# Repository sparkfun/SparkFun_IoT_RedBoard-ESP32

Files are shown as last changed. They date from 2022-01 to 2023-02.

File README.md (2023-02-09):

SparkFun IoT RedBoard - ESP32
========================================

SparkFun IoT RedBoard - ESP32 (https://www.sparkfun.com/products/19177)

[*SparkFun IoT RedBoard - ESP32 (WRL-19177)*](https://www.sparkfun.com/products/19177)

The [SparkFun IoT RedBoard](www.sparkfun.com/products/19177) is an ESP32 Development Board that includes everything but the kitchen sink! Espressif's ESP32 WROOM is a powerful WiFi and Bluetooth® MCU module that targets a wide variety of applications. At the core of this module is the ESP32-D0WDQ6 chip which is designed to be both scalable and adaptive. The IoT RedBoard can target a wide variety of applications, ranging from low-power sensor networks to the most demanding tasks, such as voice encoding, music streaming, and MP3 decoding. The IoT ReadBoard also utilizes our handy Qwiic Connect System which means no soldering or shields are required to connect it to the rest of your system!

The USB-to-serial is achieved with a USB-C connector with through hole anchoring and the ubiquitous CH340G requiring fewer driver installs. We've included 3.3V voltage translation and a [Qwiic connector](https://www.sparkfun.com/qwiic) to the edge of the board to allow for quick and seamless connection to our ever-growing line of I<sup>2</sup>C based [Qwiic products](https://www.sparkfun.com/qwiic#products). The board even includes a microSD socket if your application requires you to log and save data to a memory card.

The operating system is freeRTOS with LwIP; TLS 1.2 with hardware acceleration is built in as well. Secure (encrypted) over the air (OTA) upgrade is also supported, so that users can upgrade their products even after their release, at minimum cost and effort.

Repository Contents
-------------------

* **/Documents** - Data sheets, additional product information
* **/Hardware** - Eagle design files (.brd, .sch)

Documentation
--------------
* **[SparkFun Fritzing Part](https://github.com/sparkfun/Fritzing_Parts/blob/main/products/19177_sfe_iot_redboard_esp32_development_board.fzpz)** - Fritzing diagrams for SparkFun products.
* **[Hookup Guide](https://learn.sparkfun.com/tutorials/iot-redboard-esp32-development-board-hookup-guide)** - Basic hookup guide for the SparkFun IoT RedBoard ESP32.

License Information
-------------------

This product is _**open source**_! 

Please review the LICENSE.md file for license information. 

If you have any questions or concerns on licensing, please contact technical support on our [SparkFun forums](https://forum.sparkfun.com/viewforum.php?f=152).

Distributed as-is; no warranty is given.

- Your friends at SparkFun.

_<COLLABORATION CREDIT>_

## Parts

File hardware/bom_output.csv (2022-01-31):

Qty | PROD_ID | Names | Value | Package
9 | CAP-00810 | C1; C2; C4; C5; C7; C11; C12; C13; C17 | 0.1uF | 0603
2 | CAP-11015 | C3; C14 | 10uF | 0603
2 | CAP-00811 | C6; C10 | 10uF | EIA3216
1 | CAP-00867 | C8 | 10nF | 0603
1 | CAP-08478 | C9 | 47uF | PANASONIC_D
2 | CAP-14106 | C15; C16 | 4.7uF | 0603
1 | DIO-08053 | D1 | 1A/40V/500mV | SMA-DIODE
1 | DIO-00862 | D2 | GREEN | LED-1206-HIDDENSILK
1 | DIO-09909 | D3 | YELLOW | LED-1206-HIDDENSILK
1 | DIO-09912 | D4 | RED | LED-1206-HIDDENSILK
1 | DIO-00862 | D5 | PWR | LED-1206-HIDDENSILK
1 | DIO-09911 | D6 | BLUE | LED-1206-HIDDENSILK
1 | RES-14313 | F1 | 6V/2A | 1210
1 | CONN-08106 | J1 | 5.5x2.1mm Barrel | POWER_JACK_SMD
1 | CONN-14122 | J2 | USB C | USB-C-16P-2LAYER-PADS
1 | CONN-11219 | J5 | M10NO_SILK | 1X10_NO_SILK
1 | CONN-11219 | J6 |  | 1X10_SMD_COMBINED
2 | CONN-08438 | J7; J9 |  | 1X08_NO_SILK
2 | CONN-10204 | J8; J10 |  | 1X08_SMD_COMBINED
1 | CONN-08437 | J11 |  | 1X06_NO_SILK
1 | CONN-10203 | J12 |  | 1X06_SMD_STRAIGHT_COMBO
1 | CONN-13694 | J13 | QWIIC_RIGHT_ANGLE | JST04_1MM_RA
1 | CONN-16110 | J15 | MICRO-SD-PUSH-PUSH-EXT-PIN | MICROSD-EXTERNALPIN
1 | CONN-11443 | JP2 | LiPo | JST-2-SMD
1 | TRANS-13337 | Q1 | MBT3904DW1T1 | SC70-6
1 | TRANS-13337 | Q2 |  | SC70-6
6 | TRANS-14388 | Q3; Q5; Q7; Q9; Q11; Q13 | 20V/4.2A/52mΩ/1.4W | SOT23-3
5 | TRANS-14386 | Q4; Q6; Q8; Q10; Q12 |  | SOT363_PHILIPS
13 | RES-00824 | R1; R6; R7; R8; R12; R13; R14; R15; R17; R19; R23; R24; R26 | 10k | 0603
2 | RES-12083 | R2; R3 | 5.1k | 0603
3 | RES-07857 | R4; R5; R9 | 4.7k | 0603
1 | RES-07849 | R10 | 240 | 0603
1 | RES-07850 | R11 | 715 | 0603
5 | RES-07871 | R16; R18; R20; R25; R27 | 47k | 0603
1 | RES-07856 | R21 | 1k | 0603
1 | RES-08296 | R22 | 2.0k | 0603
2 | RES-08272 | R28; R29 | 2.2k | 0603
1 | RES-07863 | R30 | 100 | 0603
1 | SWCH-14139 | S1 | Reset | TACTILE_SWITCH_SMD_5.2MM
1 | SWCH-14139 | S2 | GPIO0 | TACTILE_SWITCH_SMD_5.2MM
1 | IC-15676 | U1 | ESP-WROOM-3232D-NARROW | ESP-WROOM-32D-NARROW
1 | IC-14038 | U2 | CH340C | SO016
1 | VREG-08170 | U3 | LM1117 | SOT223
1 | VREG-12457 | U4 | 3.3V | SOT23-5
1 | IC-09995 | U5 | MCP73831 | SOT23-5
1 | IC-12551 | U6 | MAX17048 | DFN-8

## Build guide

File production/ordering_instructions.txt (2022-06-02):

panel size, 394x132mm
PCB thickness, 1.6mm
number of layers, 4
soldermask color, Red
silkscreen color, White
oz copper, 1oz
finish, HASL lead free
stencils, top
pcs per panel, 10
min trace width, 0.1778mm / 0.0070in
min drill size, 0.3048mm / 0.0120in
filename to layer stackup 1/2/3/4: GTL, GL2, GL3, GBL

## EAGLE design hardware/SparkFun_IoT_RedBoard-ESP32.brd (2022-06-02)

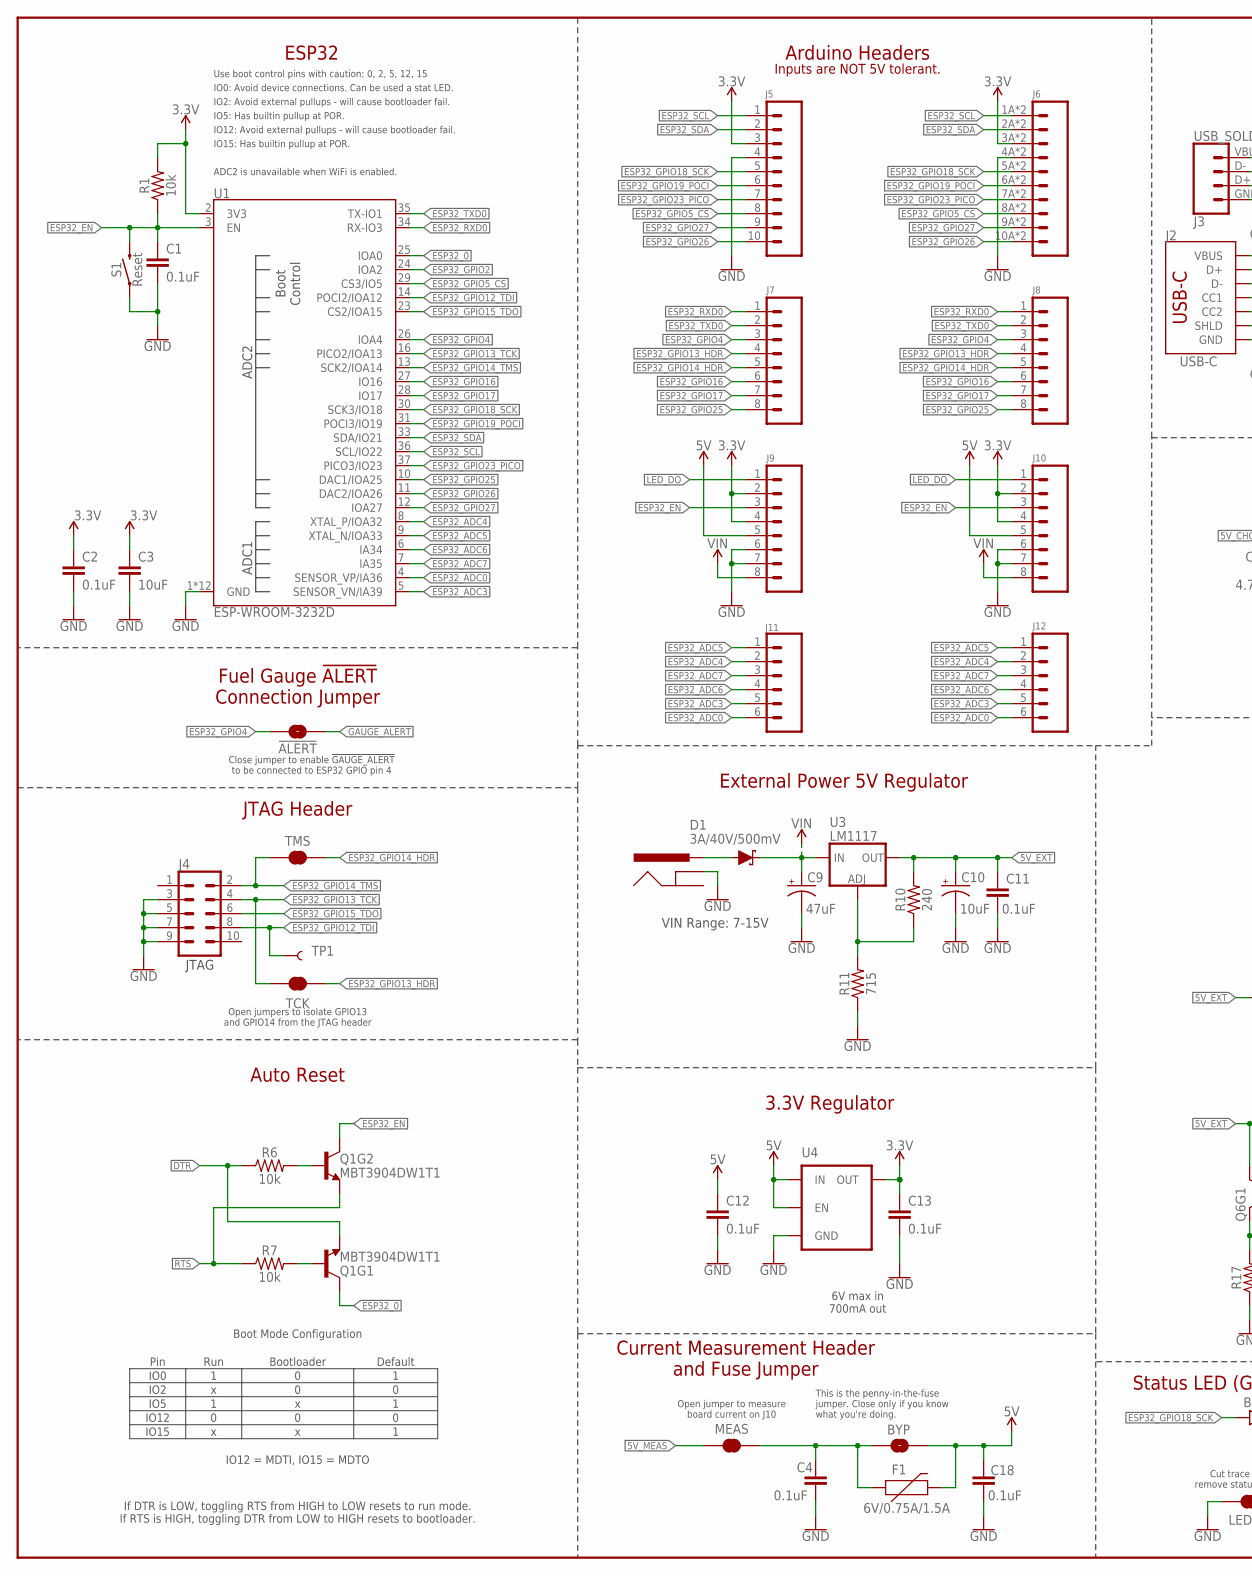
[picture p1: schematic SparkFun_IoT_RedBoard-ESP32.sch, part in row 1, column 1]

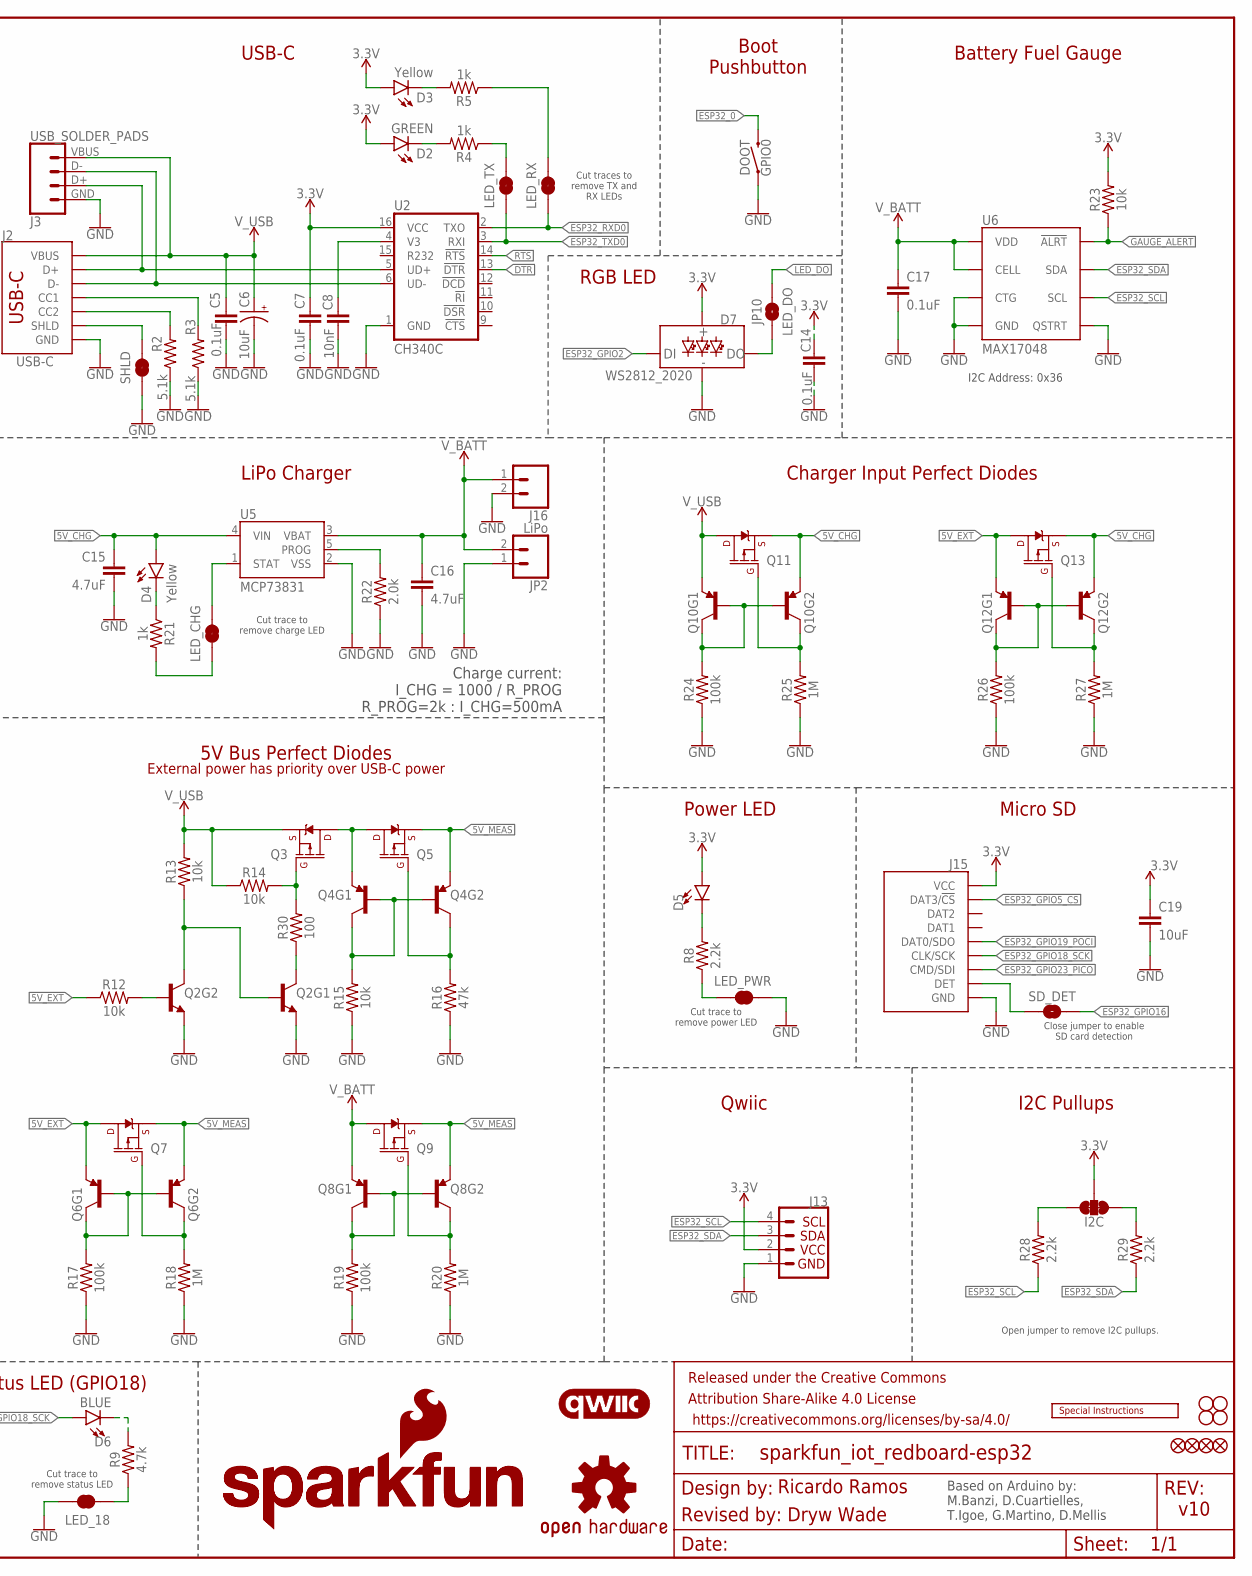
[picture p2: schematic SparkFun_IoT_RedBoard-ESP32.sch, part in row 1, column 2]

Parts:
!ALERT!: JUMPER-SMT_2_NO_SILK; SMT-JUMPER_2_NO_SILK
BYP: JUMPER-SMT_2_NO_SILK; SMT-JUMPER_2_NO_SILK
C1, C2, C4, C5, C7, C11, C12, C13, C14, C17, C18: 0.1uF; 0603
C3, C19: 10uF; 0603
C6, C10: 10uF; EIA3216
C8: 10nF; 0603
C9: 47uF; PANASONIC_D
C15, C16: 4.7uF; 0603
D1: 3A/40V/500mV; SMA-DIODE
D2: GREEN; LED-1206
D3, D4: Yellow; LED-1206
D5: RED; LED-1206
D6: BLUE; LED-1206
D7: WS2812_2020; WS2812-2020
DOOT: GPIO0; TACTILE_SWITCH_SMD_5.2MM
F1: 6V/0.75A/1.5A; 1206
FRAME1: FRAME-LEDGER; CREATIVE_COMMONS
I2C: JUMPER-SMT_3_2-NC_TRACE_SILK; SMT-JUMPER_3_2-NC_TRACE_SILK
J1: 5.5x2.1mm Barrel; POWER_JACK_SMD
J2: USB-C; USB-C-16P-4LAYER-ISOLATED
J3: USB_SOLDER_PADS; USB-SOLDER-PADS
J4: CONN_05X20.05_IN_PTH_SILK; 2X5_PTH_SILK_.05
J5: M10NO_SILK; 1X10_NO_SILK
J6: CONN_10SMD_COMBO-FEMALE; 1X10_SMD_COMBINED
J7, J9: CONN_08NO_SILK_FEMALE_PTH; 1X08_NO_SILK
J8, J10: CONN_08SMD-COMBO-FEMALE; 1X08_SMD_COMBINED
J11: CONN_06NO_SILK_FEMALE_PTH; 1X06_NO_SILK
J12: CONN_06SMD-STRAIGHT-COMBO-FEMALE; 1X06_SMD_STRAIGHT_COMBO
J13: QWIIC_RIGHT_ANGLE; JST04_1MM_RA
J15: MICRO-SD-PUSH-PUSH-EXT-PIN; MICROSD-EXTERNALPIN
J16: CONN_021X02_NO_SILK; 1X02_NO_SILK
JP1, JP7, JP8, JP9: FIDUCIAL1X2; FIDUCIAL-1X2
JP2: LiPo; JST-2-SMD
JP3, JP4, JP5, JP6: STAND-OFF
JP10: LED_DO; SMT-JUMPER_2_NO_SILK
LED_18: JUMPER-SMT_2_NC_TRACE_SILK; SMT-JUMPER_2_NC_TRACE_SILK
LED_CHG: JUMPER-SMT_2_NC_TRACE_SILK; SMT-JUMPER_2_NC_TRACE_SILK
LED_PWR: JUMPER-SMT_2_NC_TRACE_SILK; SMT-JUMPER_2_NC_TRACE_SILK
LED_RX: JUMPER-SMT_2_NC_TRACE_SILK; SMT-JUMPER_2_NC_TRACE_SILK
LED_TX: JUMPER-SMT_2_NC_TRACE_SILK; SMT-JUMPER_2_NC_TRACE_SILK
LOGO1: SFE_LOGO_NAME.1_INCH; SFE_LOGO_NAME_.1
LOGO2: QWIIC_LOGO_5MM; QWIIC_5MM
LOGO3: OSHW-LOGOMINI; OSHW-LOGO-MINI
LOGO5: SPECIAL_INSTRUCTIONS-ORDERING; ORDERING_INSTRUCTIONS
LOGO6: SFE_LOGO_NAME_FLAME.2_INCH; SFE_LOGO_NAME_FLAME_.2
MEAS: JUMPER-COMBO_2_NC_TRACE; COMBO-JUMPER_2_NC_TRACE
Q1: MBT3904DW1T1; SC70-6
Q2: TRANS_NPN_DUAL-MBT3904DW1T1; SC70-6
Q3, Q5, Q7, Q9, Q11, Q13: 20V/4.2A/52mΩ/1.4W; SOT23-3
Q4, Q6, Q8, Q10, Q12: TRANS_PNP_DUALSOT-363; SOT363_PHILIPS
R1, R6, R7, R12, R13, R14, R15, R23: 10k; 0603
R2, R3: 5.1k; 0603
R4, R5, R21: 1k; 0603
R8, R28, R29: 2.2k; 0603
R9: 4.7k; 0603
R10: 240; 0603
R11: 715; 0603
R16: 47k; 0603
R17, R19, R24, R26: 100k; 0603
R18, R20, R25, R27: 1M; 0603
R22: 2.0k; 0603
R30: 100; 0603
S1: Reset; TACTILE_SWITCH_SMD_5.2MM
SD_DET: SD_DET; SMT-JUMPER_2_NO_SILK
SHLD: SHLD; SMT-JUMPER_2_NC_TRACE_SILK
TCK: JUMPER-SMT_2_NC_TRACE_SILK; SMT-JUMPER_2_NC_TRACE_SILK
TMS: JUMPER-SMT_2_NC_TRACE_SILK; SMT-JUMPER_2_NC_TRACE_SILK
TP1: TEST-POINT3; PAD.03X.03
U1: ESP-WROOM-3232D; ESP-WROOM-32D
U2: CH340C; SO016
U3: LM1117; SOT223
U4: XC6222B331MR-G; SOT23-5
U5: MCP73831; SOT23-5
U6: MAX17048; DFN-8

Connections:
3.3V: C2.1, C3.1, C7.1, C13.1, C14.1, C19.1, D2.A, D3.A, D5.A, D7.VCC, I2C.2, J5.3, J6.3A (3), J6.3B (3), J9.2, J9.4, J10.2, J10.4, J13.2, J15.4 (VCC), R1.2, R23.2, U1.2 (3V3), U2.16 (VCC), U4.5 (OUT)
5V: BYP.2, C12.1, C18.1, F1.2, J9.5, J10.5, U4.1 (IN), U4.3 (EN)
5V_CHG: C15.1, D4.A, Q10.4 (E), Q11.2 (S), Q12.4 (E), Q13.2 (S), U5.4 (VIN)
5V_EXT: C10.+, C11.1, Q6.1 (E), Q7.3 (D), Q12.1 (E), Q13.3 (D), R10.2, R12.1, U3.2 (OUT), U3.4 (OUT)
5V_MEAS: MEAS.1, MEAS.3 (1), Q4.4 (E), Q5.2 (S), Q6.4 (E), Q7.2 (S), Q8.4 (E), Q9.2 (S)
!DTR!: Q1.4 (E), R6.1, U2.13 (!DTR)
!GAUGE_ALERT!: !ALERT!.1, R23.1, U6.5 (!ALRT)
!RTS!: Q1.1 (E), R7.1, U2.14 (!RTS)
CC1: J2.A5 (CC1), R3.2
CC2: J2.B5 (CC2), R2.2
D+: J2.A6 (D+), J2.B6 (D+), J3.D+ (3), U2.5 (UD+)
D-: J2.A7 (D-), J2.B7 (D-), J3.D- (2), U2.6 (UD-)
ESP32_0: DOOT.3 (2), DOOT.4 (2), Q1.3 (C), U1.25 (IOA0)
ESP32_ADC0: J11.6, J12.6, U1.4 (SENSOR_VP/IA36)
ESP32_ADC3: J11.5, J12.5, U1.5 (SENSOR_VN/IA39)
ESP32_ADC4: J11.2, J12.2, U1.8 (XTAL_P/IOA32)
ESP32_ADC5: J11.1, J12.1, U1.9 (XTAL_N/IOA33)
ESP32_ADC6: J11.4, J12.4, U1.6 (IA34)
ESP32_ADC7: J11.3, J12.3, U1.7 (IA35)
ESP32_EN: C1.1, J9.3, J10.3, Q1.6 (C), R1.1, S1.3 (2), S1.4 (2), U1.3 (EN)
ESP32_GPIO2: D7.DI, U1.24 (IOA2)
ESP32_GPIO4: !ALERT!.2, J7.3, J8.3, U1.26 (IOA4)
ESP32_GPIO5_!CS!: J5.8, J6.8A (8), J6.8B (8), J15.2 (DAT3/!CS!), U1.29 (CS3/IO5)
ESP32_GPIO12_TDI: J4.8, TP1.1, U1.14 (POCI2/IOA12)
ESP32_GPIO13_HDR: J7.4, J8.4, TCK.2
ESP32_GPIO13_TCK: J4.4, TCK.1, U1.16 (PICO2/IOA13)
ESP32_GPIO14_HDR: J7.5, J8.5, TMS.2
ESP32_GPIO14_TMS: J4.2, TMS.1, U1.13 (SCK2/IOA14)
ESP32_GPIO15_TDO: J4.6, U1.23 (CS2/IOA15)
ESP32_GPIO16: J7.6, J8.6, SD_DET.2, U1.27 (IO16)
ESP32_GPIO17: J7.7, J8.7, U1.28 (IO17)
ESP32_GPIO18_SCK: D6.A, J5.5, J6.5A (5), J6.5B (5), J15.5 (CLK/SCK), U1.30 (SCK3/IO18)
ESP32_GPIO19_POCI: J5.6, J6.6A (6), J6.6B (6), J15.7 (DAT0/SDO), U1.31 (POCI3/IO19)
ESP32_GPIO23_PICO: J5.7, J6.7A (7), J6.7B (7), J15.3 (CMD/SDI), U1.37 (PICO3/IO23)
ESP32_GPIO25: J7.8, J8.8, U1.10 (DAC1/IOA25)
ESP32_GPIO26: J5.10, J6.10A (10), J6.10B (10), U1.11 (DAC2/IOA26)
ESP32_GPIO27: J5.9, J6.9A (9), J6.9B (9), U1.12 (IOA27)
ESP32_RXD0: J7.1, J8.1, LED_RX.1, U1.34 (RX-IO3), U2.2 (TXO)
ESP32_SCL: J5.1, J6.1A (1), J6.1B (1), J13.4, R28.1, U1.36 (SCL/IO22), U6.7 (SCL)
ESP32_SDA: J5.2, J6.2A (2), J6.2B (2), J13.3, R29.1, U1.33 (SDA/IO21), U6.8 (SDA)
ESP32_TXD0: J7.2, J8.2, LED_TX.1, U1.35 (TX-IO1), U2.3 (RXI)
GND: C1.2, C2.2, C3.2, C4.2, C5.2, C6.-, C7.2, C8.2, C9.-, C10.-, C11.2, C12.2, C13.2, C14.2, C15.2, C16.2, C17.2, C18.2, C19.2, D7.GND, DOOT.1, DOOT.2 (1), J1.GND (GNDBREAK), J2.GND, J2.GND2 (GND), J3.GND (4), J4.3, J4.5, J4.7, J4.9, J5.4, J6.4A (4), J6.4B (4), J9.6, J9.7, J10.6, J10.7, J13.1, J15.6 (GND), J15.10 (GND), J15.11 (GND), J15.12 (GND), J15.13 (GND), J16.2, JP2.1 (2), LED_18.1, LED_PWR.1, Q2.1 (E), Q2.4 (E), R2.1, R3.1, R11.1, R15.1, R16.1, R17.1, R18.1, R19.1, R20.1, R22.1, R24.1, R25.1, R26.1, R27.1, S1.1, S1.2 (1), SHLD.1, U1.1 (GND), U1.15 (GND), U1.38 (GND), U1.GND, U1.GNDT1 (GND), U1.GNDT2 (GND), U1.GNDT3 (GND), U1.GNDT4 (GND), U1.GNDT5 (GND), U1.GNDT6 (GND), U1.GNDT7 (GND), U1.GNDT8 (GND), U2.1 (GND), U4.2 (GND), U5.2 (VSS), U6.1 (CTG), U6.4 (GND), U6.6 (QSTRT), U6.9 (GND)
LED_DO: J9.1, J10.1, JP10.2
unnamed: LED_CHG.2, U5.1 (STAT)
unnamed: D5.C, R8.2
unnamed: D6.C, R9.2
unnamed: LED_CHG.1, R21.2
unnamed: D2.C, R4.2
unnamed: C8.1, U2.4 (V3)
unnamed: D3.C, R5.2
unnamed: Q6.2 (B), Q6.5 (B), Q6.6 (C), R17.2
unnamed: Q3.1 (G), R14.2, R30.2
unnamed: Q6.3 (C), Q7.1 (G), R18.2
unnamed: Q2.3 (C), R30.1
unnamed: Q4.2 (B), Q4.5 (B), Q4.6 (C), R15.2
unnamed: Q8.2 (B), Q8.5 (B), Q8.6 (C), R19.2
unnamed: R22.2, U5.5 (PROG)
unnamed: R10.1, R11.2, U3.1 (ADJ)
unnamed: Q4.3 (C), Q5.1 (G), R16.2
unnamed: Q8.3 (C), Q9.1 (G), R20.2
unnamed: I2C.3, R28.2
unnamed: BYP.1, C4.1, F1.1, MEAS.2, MEAS.4 (2)
unnamed: I2C.1, R29.2
unnamed: Q2.2 (B), R12.2
unnamed: Q2.5 (B), Q2.6 (C), R13.1
unnamed: Q10.3 (C), Q11.1 (G), R25.2
unnamed: Q1.5 (B), R7.2
unnamed: Q1.2 (B), R6.2
unnamed: Q10.2 (B), Q10.5 (B), Q10.6 (C), R24.2
unnamed: J15.9 (DET), SD_DET.1
unnamed: Q12.3 (C), Q13.1 (G), R27.2
unnamed: Q12.2 (B), Q12.5 (B), Q12.6 (C), R26.2
unnamed: LED_TX.2, R4.1
unnamed: LED_RX.2, R5.1
unnamed: D4.C, R21.1
unnamed: LED_PWR.2, R8.1
unnamed: LED_18.2, R9.1
unnamed: D7.DO, JP10.1
PWRIN: D1.A, J1.VIN0 (PWR)
SHLD: J2.SHLD1 (SHLD), J2.SHLD2 (SHLD), J2.SHLD3 (SHLD), J2.SHLD4 (SHLD), J2.SHLD5 (SHLD), J2.SHLD6 (SHLD), J2.SHLD7 (SHLD), J2.SHLD8 (SHLD), SHLD.2
VIN: C9.+, D1.C, J9.8, J10.8, U3.3 (IN)
VUSB_PROT: Q3.3 (D), Q4.1 (E), Q5.3 (D)
V_BATT: C16.1, C17.1, J16.1, JP2.2 (1), Q8.1 (E), Q9.3 (D), U5.3 (VBAT), U6.2 (CELL), U6.3 (VDD)
V_USB: C5.1, C6.+, J2.VBUS1 (VBUS), J2.VBUS2 (VBUS), J3.VBUS (1), Q3.2 (S), Q10.1 (E), Q11.3 (D), R13.2, R14.1

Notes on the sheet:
Based on Arduino by: M.Banzi, D.Cuartielles, T.Igoe, G.Martino, D.Mellis
Ricardo Ramos
v10
This is the penny-in-the-fuse jumper. Close only if you know what you're doing.
JTAG
J12
J11
J10
If DTR is LOW, toggling RTS from HIGH to LOW resets to run mode. If RTS is HIGH, toggling DTR from LOW to HIGH resets to bootloader.
VIN Range: 7-15V
6V max in 700mA out
Charge current: I_CHG = 1000 / R_PROG R_PROG=2k : I_CHG=500mA
ESP32
Arduino Headers
USB-C
Battery Fuel Gauge
LiPo Charger
Charger Input Perfect Diodes
5V Bus Perfect Diodes
Power LED
Micro SD
Qwiic
I2C Pullups
External Power 5V Regulator
3.3V Regulator
JTAG Header
Fuel Gauge !ALERT! Connection Jumper
Auto Reset
Current Measurement Header and Fuse Jumper
Boot Pushbutton
Status LED (GPIO18)
External power has priority over USB-C power
Inputs are NOT 5V tolerant.
I2C Address: 0x36
Open jumpers to isolate GPIO13 and GPIO14 from the JTAG header
Close jumper to enable !GAUGE_ALERT! to be connected to ESP32 GPIO pin 4
Open jumper to measure board current on J10
Open jumper to remove I2C pullups.
Revised by: Dryw Wade
RGB LED

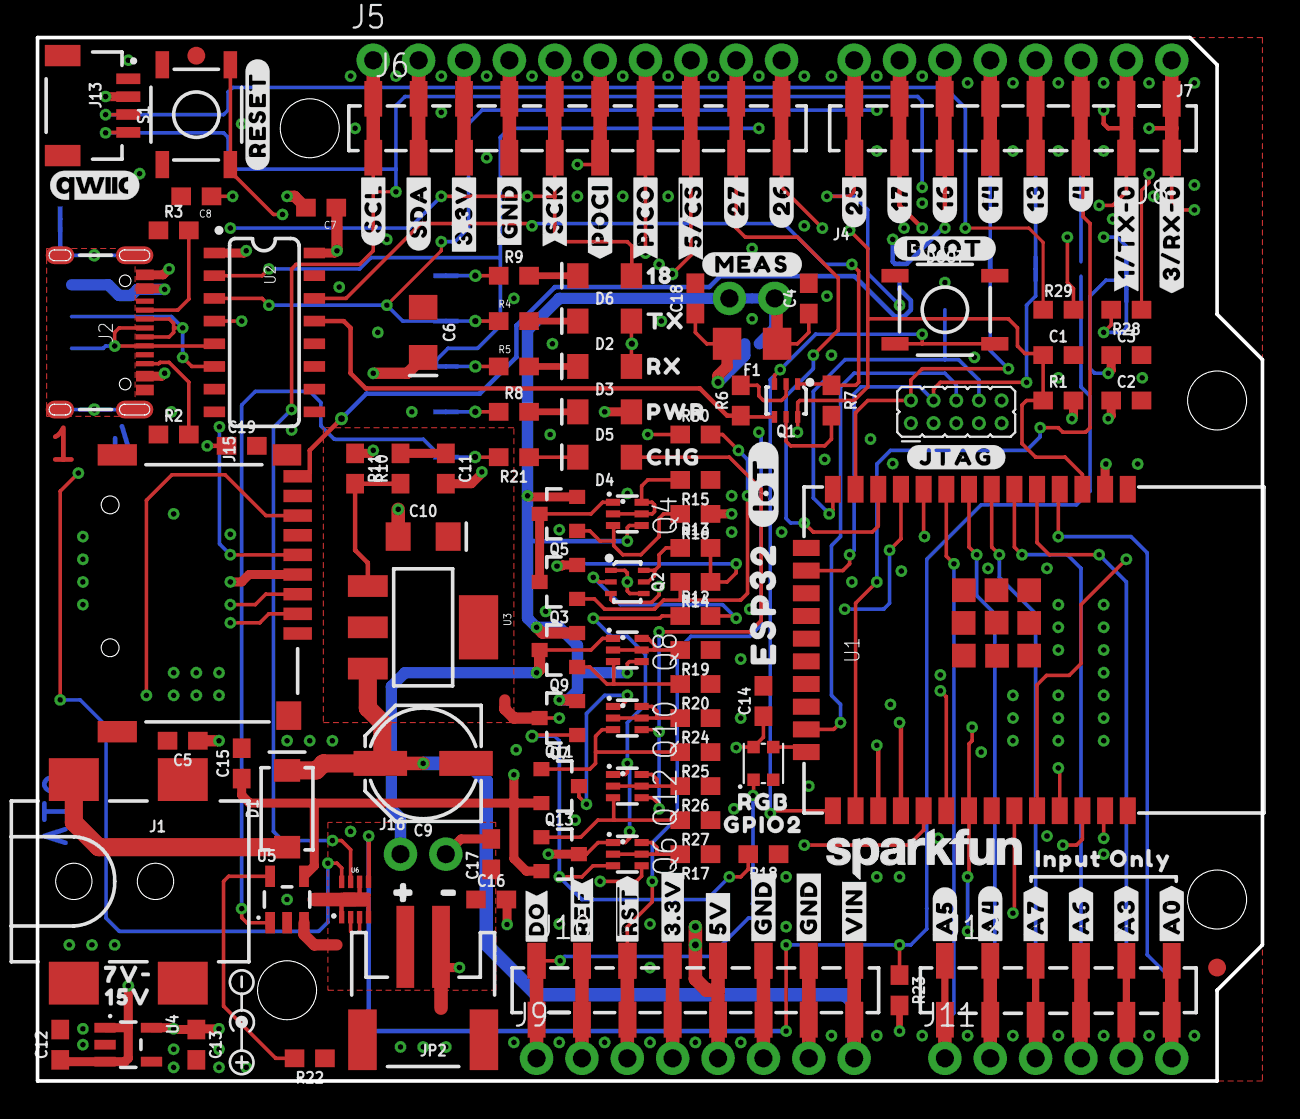
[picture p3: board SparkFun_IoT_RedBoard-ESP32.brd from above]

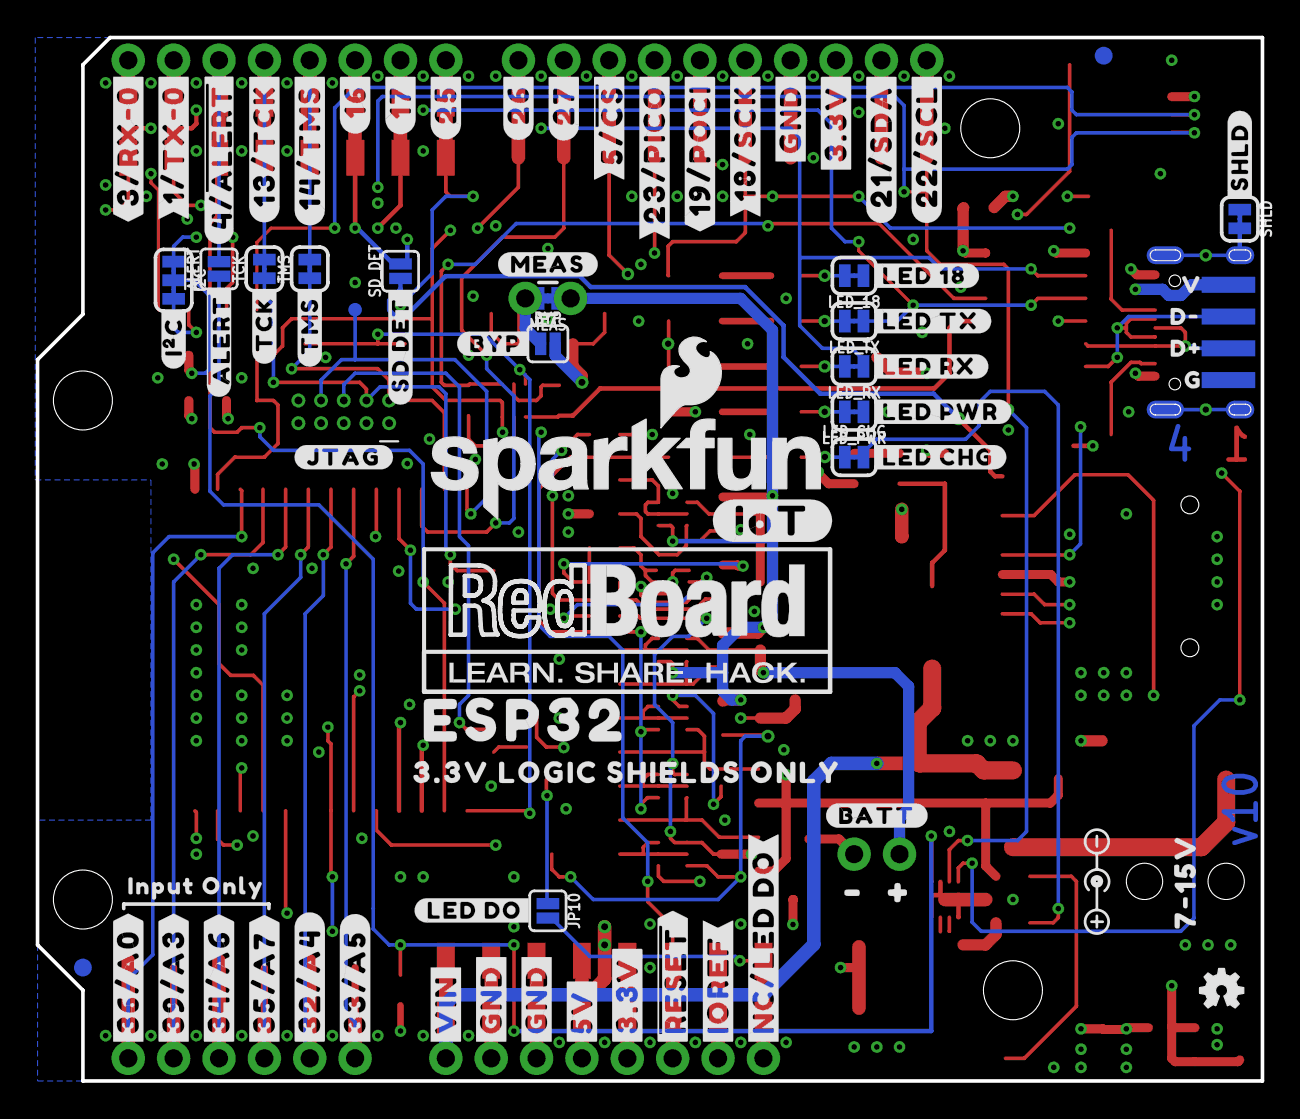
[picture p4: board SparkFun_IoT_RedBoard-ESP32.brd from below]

Board: 4 copper layers, 68.6 x 58.4 mm, 235 parts (81 on the bottom side), 84 nets.

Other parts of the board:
U$3: #SCL#34
U$4: #SDA#33
U$5: #3#3V#33
U$6: #GND#32
U$7: #SCK#31
U$8: #POCI#30
U$9: #PICO#29
U$10: 1836
U$11, U$42: #MEAS#1851
U$12: #27#27
U$13: #26#26
U$14: TX1838
U$15: RX1839
U$16: PWR1837
U$17: CHG1840
U$18: #25#18
U$19: #17#17
U$20: #16#15
U$21: #14#14
U$22: #13#5
U$23: #4#2
U$24: #3#RX#0#4
U$25: #3#RX#0#0
U$26: #RESET#1842
U$27: #BOOT#1841
U$28, U$46: #JTAG#1847
U$29: #A0#1843
U$30: #A3#1843
U$31: #A6#1843
U$32: #A7#1843
U$33: #A4#1843
U$34: #A5#1843
U$35: #VIN#1843
U$36, U$37: #GND#1844
U$38: #5V#1845
U$39: #3#3V#1845
U$40: ##RST##1845
U$41: #REF#1846
U$43, U$86: #1849
U$44, U$88: #1850
U$45: #BATT#1848
U$47: #IOT#132321874
U$48: ESP321855
U$49: #LED_18#0
U$50: #39#A3#321862
U$51: #36#A0#321862
U$52: #33#A5#0
U$53: #35#A7#321862
U$54: #32#A4#32321865
U$55: #34#A6#321862
U$56: #VIN#321862
U$57, U$60: #GND#321863
U$58: #5V#321864
U$59: #3#3V#321864
U$61: ##RESET##321864
U$62: #IOREF#321865
U$63: #5##CS##0
U$64: #BYP#0
U$65: RGB0
U$66: #13#TCK#32321869
U$67: #14#TMS#32321869
U$68: #16#32321869
U$69: #17#32321869
U$70: #25#32321869
U$71: #26#32321869
U$72: #5##CS##32321869
U$73: #23#PICO#321866
U$74: #19#POCI#321866
U$75: #18#SCK#32321869
U$76: #21#SDA#32321869
U$77: #22#SCL#32321869
U$78: #27#32321869
U$79: #GND#321866
U$80: #3#3V#321866
U$81: #SHLD#0
U$82: #I�C#0
U$83: D#32321863
U$84: D#32321862
U$85: G32321864
U$87: V323252
U$89: #DO#0
U$90: ##ALERT##1852
U$91: #TMS#1854
U$92: #TCK#1853
U$93: ESP32321856
U$94, U$99: POLARITY_MARKING_CENTER_POSITIVE#JPG
U$96, U$97: INPUT_ONLY321867
U$98: REDBOARD_LOGO
U$100: #IOT#132321869
U$101: 7#15V32321861
U$102: #4##ALERT##0
U$103: 3#3V_LOGIC_SHIELDS_ONLY132321876
U$104: #1#TX#0#0
U$105: #1#TX#0#2
U$106: 7V#0
U$107: 15V0
U$108: #SD_DET#0
U$109: #LED_TX#0
U$110: #LED_RX#0
U$111: #LED_PWR#0
U$112: #LED_CHG#0
U$113: GPIO20
U$114: #LED_DO#1
U$115: #NC#LED_DO#0

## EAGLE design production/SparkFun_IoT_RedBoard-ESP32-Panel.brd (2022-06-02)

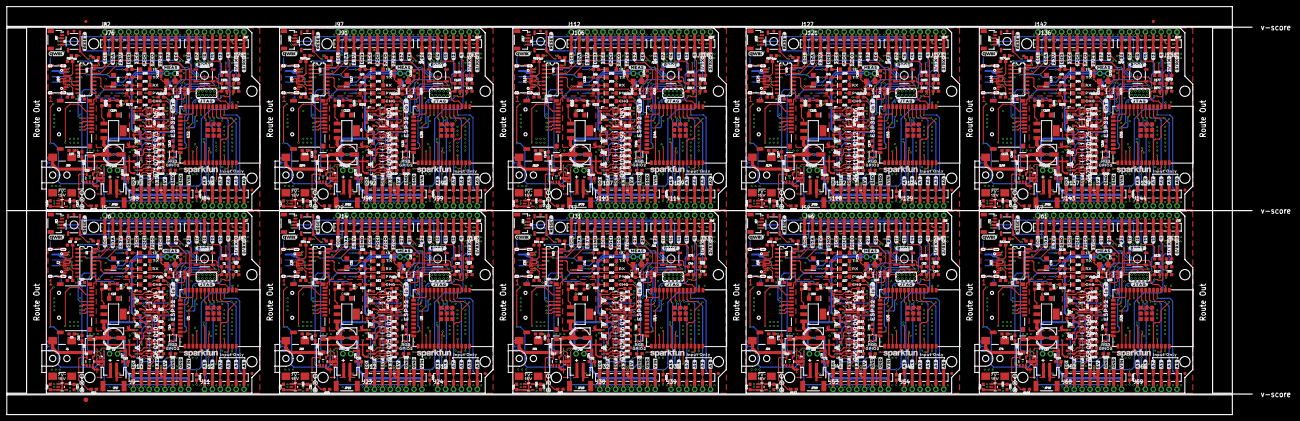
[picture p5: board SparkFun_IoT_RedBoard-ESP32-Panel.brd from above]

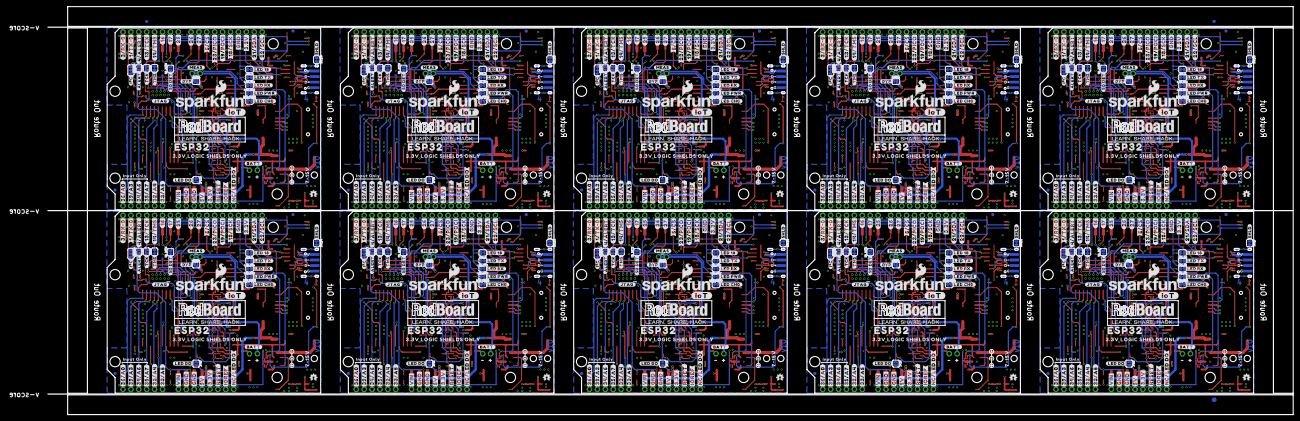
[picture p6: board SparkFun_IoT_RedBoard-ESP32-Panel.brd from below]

Board: 4 copper layers, 400.1 x 131.1 mm, 2336 parts (813 on the bottom side), 840 nets.

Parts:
!ALERT!, !ALERT!1, !ALERT!2, !ALERT!3, !ALERT!4, !ALERT!5, !ALERT!6, !ALERT!7, !ALERT!8, !ALERT!9: JUMPER-SMT_2_NO_SILK; SMT-JUMPER_2_NO_SILK
BYP, BYP1, BYP2, BYP3, BYP4, BYP5, BYP6, BYP7, BYP8, BYP9: JUMPER-SMT_2_NO_SILK; SMT-JUMPER_2_NO_SILK
C1, C2, C4, C5, C7, C11, C12, C13, C14, C17, C18, C20, C21, C24, C25, C26, C29, C31, C32, C35, C36, C37, C39, C40, C43, C44, C45, C48, C50, C51, C54, C55, C56, C58, C59, C62, C63, C64, C67, C69, C70, C73, C74, C75, C77, C78, C81, C82, C83, C86, C88, C89, C92, C93, C94, C96, C97, C100, C101, C102, C105, C107, C108, C111, C112, C113, C115, C116, C119, C120, C121, C124, C126, C127, C130, C131, C132, C134, C135, C138, C139, C140, C143, C145, C146, C149, C150, C151, C153, C154, C157, C158, C159, C162, C164, C165, C168, C169, C170, C172, C173, C176, C177, C178, C181, C183, C184, C187, C188, C189: 0.1uF; 0603
C3, C19, C27, C38, C46, C57, C65, C76, C84, C95, C103, C114, C122, C133, C141, C152, C160, C171, C179, C190: 10uF; 0603
C6, C10, C22, C28, C41, C47, C60, C66, C79, C85, C98, C104, C117, C123, C136, C142, C155, C161, C174, C180: 10uF; EIA3216
C8, C23, C42, C61, C80, C99, C118, C137, C156, C175: 10nF; 0603
C9, C30, C49, C68, C87, C106, C125, C144, C163, C182: 47uF; PANASONIC_D
C15, C16, C33, C34, C52, C53, C71, C72, C90, C91, C109, C110, C128, C129, C147, C148, C166, C167, C185, C186: 4.7uF; 0603
D1, D11, D18, D25, D32, D39, D46, D53, D60, D67: 3A/40V/500mV; SMA-DIODE
D2, D8, D15, D22, D29, D36, D43, D50, D57, D64: GREEN; LED-1206
D3, D4, D9, D12, D16, D19, D23, D26, D30, D33, D37, D40, D44, D47, D51, D54, D58, D61, D65, D68: Yellow; LED-1206
D5, D13, D20, D27, D34, D41, D48, D55, D62, D69: RED; LED-1206
D6, D10, D17, D24, D31, D38, D45, D52, D59, D66: BLUE; LED-1206
D7, D14, D21, D28, D35, D42, D49, D56, D63, D70: WS2812_2020; WS2812-2020
DOOT, DOOT1, DOOT2, DOOT3, DOOT4, DOOT5, DOOT6, DOOT7, DOOT8, DOOT9: GPIO0; TACTILE_SWITCH_SMD_5.2MM
E$1, E$2, E$3, E$4: FIDUCIAL-1X2
E$5, E$6: FIDUCIAL-1.5X3
F1, F2, F3, F4, F5, F6, F7, F8, F9, F10: 6V/0.75A/1.5A; 1206
I2C, I2C1, I2C2, I2C3, I2C4, I2C5, I2C6, I2C7, I2C8, I2C9: JUMPER-SMT_3_2-NC_TRACE_SILK; SMT-JUMPER_3_2-NC_TRACE_SILK
J1, J29, J44, J59, J74, J89, J104, J119, J134, J149: 5.5x2.1mm Barrel; POWER_JACK_SMD
J2, J20, J35, J50, J65, J80, J95, J110, J125, J140: USB-C; USB-C-16P-4LAYER-ISOLATED
J3, J21, J36, J51, J66, J81, J96, J111, J126, J141: USB_SOLDER_PADS; USB-SOLDER-PADS
J4, J26, J41, J56, J71, J86, J101, J116, J131, J146: 2X5_PTH_SILK_.05
J5, J22, J37, J52, J67, J82, J97, J112, J127, J142: M10NO_SILK; 1X10_NO_SILK
J6, J14, J31, J46, J61, J76, J91, J106, J121, J136: 1X10_SMD_COMBINED
J7, J9, J23, J25, J38, J40, J53, J55, J68, J70, J83, J85, J98, J100, J113, J115, J128, J130, J143, J145: 1X08_NO_SILK
J8, J10, J17, J18, J32, J33, J47, J48, J62, J63, J77, J78, J92, J93, J107, J108, J122, J123, J137, J138: 1X08_SMD_COMBINED
J11, J24, J39, J54, J69, J84, J99, J114, J129, J144: 1X06_NO_SILK
J12, J19, J34, J49, J64, J79, J94, J109, J124, J139: 1X06_SMD_STRAIGHT_COMBO
J13, J27, J42, J57, J72, J87, J102, J117, J132, J147: QWIIC_RIGHT_ANGLE; JST04_1MM_RA
J15, J28, J43, J58, J73, J88, J103, J118, J133, J148: MICRO-SD-PUSH-PUSH-EXT-PIN; MICROSD-EXTERNALPIN
J16, J30, J45, J60, J75, J90, J105, J120, J135, J150: 1X02_NO_SILK
JP1, JP7, JP8, JP9, JP15, JP16, JP17, JP18, JP25, JP26, JP27, JP28, JP35, JP36, JP37, JP38, JP45, JP46, JP47, JP48, JP55, JP56, JP57, JP58, JP65, JP66, JP67, JP68, JP75, JP76, JP77, JP78, JP85, JP86, JP87, JP88, JP95, JP96, JP97, JP98: FIDUCIAL1X2; FIDUCIAL-1X2
JP2, JP19, JP29, JP39, JP49, JP59, JP69, JP79, JP89, JP99: LiPo; JST-2-SMD
JP3, JP4, JP5, JP6, JP11, JP12, JP13, JP14, JP21, JP22, JP23, JP24, JP31, JP32, JP33, JP34, JP41, JP42, JP43, JP44, JP51, JP52, JP53, JP54, JP61, JP62, JP63, JP64, JP71, JP72, JP73, JP74, JP81, JP82, JP83, JP84, JP91, JP92, JP93, JP94: STAND-OFF
JP10, JP20, JP30, JP40, JP50, JP60, JP70, JP80, JP90, JP100: LED_DO; SMT-JUMPER_2_NO_SILK
LED_1, LED_2, LED_3, LED_4, LED_5, LED_6, LED_7, LED_8, LED_9, LED_18: JUMPER-SMT_2_NC_TRACE_SILK; SMT-JUMPER_2_NC_TRACE_SILK
LED_CHG, LED_CHG1, LED_CHG2, LED_CHG3, LED_CHG4, LED_CHG5, LED_CHG6, LED_CHG7, LED_CHG8, LED_CHG9: JUMPER-SMT_2_NC_TRACE_SILK; SMT-JUMPER_2_NC_TRACE_SILK
LED_PWR, LED_PWR1, LED_PWR2, LED_PWR3, LED_PWR4, LED_PWR5, LED_PWR6, LED_PWR7, LED_PWR8, LED_PWR9: JUMPER-SMT_2_NC_TRACE_SILK; SMT-JUMPER_2_NC_TRACE_SILK
LED_RX, LED_RX1, LED_RX2, LED_RX3, LED_RX4, LED_RX5, LED_RX6, LED_RX7, LED_RX8, LED_RX9: JUMPER-SMT_2_NC_TRACE_SILK; SMT-JUMPER_2_NC_TRACE_SILK
LED_TX, LED_TX1, LED_TX2, LED_TX3, LED_TX4, LED_TX5, LED_TX6, LED_TX7, LED_TX8, LED_TX9: JUMPER-SMT_2_NC_TRACE_SILK; SMT-JUMPER_2_NC_TRACE_SILK
LOGO1, LOGO4, LOGO9, LOGO13, LOGO17, LOGO21, LOGO25, LOGO29, LOGO33, LOGO37: SFE_LOGO_NAME.1_INCH; SFE_LOGO_NAME_.1
LOGO2, LOGO5, LOGO10, LOGO14, LOGO18, LOGO22, LOGO26, LOGO30, LOGO34, LOGO38: QWIIC_LOGO_5MM; QWIIC_5MM
LOGO3, LOGO7, LOGO11, LOGO15, LOGO19, LOGO23, LOGO27, LOGO31, LOGO35, LOGO39: OSHW-LOGOMINI; OSHW-LOGO-MINI
LOGO6, LOGO8, LOGO12, LOGO16, LOGO20, LOGO24, LOGO28, LOGO32, LOGO36, LOGO40: SFE_LOGO_NAME_FLAME.2_INCH; SFE_LOGO_NAME_FLAME_.2
MEAS, MEAS1, MEAS2, MEAS3, MEAS4, MEAS5, MEAS6, MEAS7, MEAS8, MEAS9: JUMPER-COMBO_2_NC_TRACE; COMBO-JUMPER_2_NC_TRACE
Q1, Q14, Q27, Q40, Q53, Q66, Q79, Q92, Q105, Q118: MBT3904DW1T1; SC70-6
Q2, Q17, Q30, Q43, Q56, Q69, Q82, Q95, Q108, Q121: SC70-6
Q3, Q5, Q7, Q9, Q11, Q13, Q16, Q18, Q20, Q22, Q24, Q26, Q29, Q31, Q33, Q35, Q37, Q39, Q42, Q44, Q46, Q48, Q50, Q52, Q55, Q57, Q59, Q61, Q63, Q65, Q68, Q70, Q72, Q74, Q76, Q78, Q81, Q83, Q85, Q87, Q89, Q91, Q94, Q96, Q98, Q100, Q102, Q104, Q107, Q109, Q111, Q113, Q115, Q117, Q120, Q122, Q124, Q126, Q128, Q130: 20V/4.2A/52mΩ/1.4W; SOT23-3
Q4, Q6, Q8, Q10, Q12, Q15, Q19, Q21, Q23, Q25, Q28, Q32, Q34, Q36, Q38, Q41, Q45, Q47, Q49, Q51, Q54, Q58, Q60, Q62, Q64, Q67, Q71, Q73, Q75, Q77, Q80, Q84, Q86, Q88, Q90, Q93, Q97, Q99, Q101, Q103, Q106, Q110, Q112, Q114, Q116, Q119, Q123, Q125, Q127, Q129: SOT363_PHILIPS
R1, R6, R7, R12, R13, R14, R15, R23, R35, R36, R37, R43, R45, R46, R47, R58, R65, R66, R67, R73, R75, R76, R77, R88, R95, R96, R97, R103, R105, R106, R107, R118, R125, R126, R127, R133, R135, R136, R137, R148, R155, R156, R157, R163, R165, R166, R167, R178, R185, R186, R187, R193, R195, R196, R197, R208, R215, R216, R217, R223, R225, R226, R227, R238, R245, R246, R247, R253, R255, R256, R257, R268, R275, R276, R277, R283, R285, R286, R287, R298: 10k; 0603
R2, R3, R33, R34, R63, R64, R93, R94, R123, R124, R153, R154, R183, R184, R213, R214, R243, R244, R273, R274: 5.1k; 0603
R4, R5, R21, R31, R32, R52, R61, R62, R82, R91, R92, R112, R121, R122, R142, R151, R152, R172, R181, R182, R202, R211, R212, R232, R241, R242, R262, R271, R272, R292: 1k; 0603
R8, R28, R29, R39, R40, R59, R69, R70, R89, R99, R100, R119, R129, R130, R149, R159, R160, R179, R189, R190, R209, R219, R220, R239, R249, R250, R269, R279, R280, R299: 2.2k; 0603
R9, R38, R68, R98, R128, R158, R188, R218, R248, R278: 4.7k; 0603
R10, R42, R72, R102, R132, R162, R192, R222, R252, R282: 240; 0603
R11, R41, R71, R101, R131, R161, R191, R221, R251, R281: 715; 0603
R16, R44, R74, R104, R134, R164, R194, R224, R254, R284: 47k; 0603
R17, R19, R24, R26, R48, R50, R54, R56, R78, R80, R84, R86, R108, R110, R114, R116, R138, R140, R144, R146, R168, R170, R174, R176, R198, R200, R204, R206, R228, R230, R234, R236, R258, R260, R264, R266, R288, R290, R294, R296: 100k; 0603
R18, R20, R25, R27, R49, R51, R55, R57, R79, R81, R85, R87, R109, R111, R115, R117, R139, R141, R145, R147, R169, R171, R175, R177, R199, R201, R205, R207, R229, R231, R235, R237, R259, R261, R265, R267, R289, R291, R295, R297: 1M; 0603
R22, R53, R83, R113, R143, R173, R203, R233, R263, R293: 2.0k; 0603
R30, R60, R90, R120, R150, R180, R210, R240, R270, R300: 100; 0603
S1, S2, S3, S4, S5, S6, S7, S8, S9, S10: Reset; TACTILE_SWITCH_SMD_5.2MM
SD_DET, SD_DET1, SD_DET2, SD_DET3, SD_DET4, SD_DET5, SD_DET6, SD_DET7, SD_DET8, SD_DET9: SD_DET; SMT-JUMPER_2_NO_SILK
SHLD, SHLD1, SHLD2, SHLD3, SHLD4, SHLD5, SHLD6, SHLD7, SHLD8, SHLD9: SHLD; SMT-JUMPER_2_NC_TRACE_SILK
TCK, TCK1, TCK2, TCK3, TCK4, TCK5, TCK6, TCK7, TCK8, TCK9: JUMPER-SMT_2_NC_TRACE_SILK; SMT-JUMPER_2_NC_TRACE_SILK
TMS, TMS1, TMS2, TMS3, TMS4, TMS5, TMS6, TMS7, TMS8, TMS9: JUMPER-SMT_2_NC_TRACE_SILK; SMT-JUMPER_2_NC_TRACE_SILK
TP1, TP2, TP3, TP4, TP5, TP6, TP7, TP8, TP9, TP10: TEST-POINT3; PAD.03X.03
U1, U8, U14, U20, U26, U32, U38, U44, U50, U56: ESP-WROOM-3232D; ESP-WROOM-32D
U2, U7, U13, U19, U25, U31, U37, U43, U49, U55: CH340C; SO016
U3, U9, U15, U21, U27, U33, U39, U45, U51, U57: LM1117; SOT223
U4, U10, U16, U22, U28, U34, U40, U46, U52, U58: XC6222B331MR-G; SOT23-5
U5, U11, U17, U23, U29, U35, U41, U47, U53, U59: MCP73831; SOT23-5
U6, U12, U18, U24, U30, U36, U42, U48, U54, U60: MAX17048; DFN-8
U$1, U$87, U$225, U$337, U$449, U$561, U$673, U$785, U$897, U$1009: V323252
U$2, U$3, U$226, U$338, U$450, U$562, U$674, U$786, U$898, U$1010: #SCL#34
U$4, U$95, U$227, U$339, U$451, U$563, U$675, U$787, U$899, U$1011: #SDA#33
U$5, U$116, U$228, U$340, U$452, U$564, U$676, U$788, U$900, U$1012: #3#3V#33
U$6, U$117, U$229, U$341, U$453, U$565, U$677, U$789, U$901, U$1013: #GND#32
U$7, U$118, U$230, U$342, U$454, U$566, U$678, U$790, U$902, U$1014: #SCK#31
U$8, U$119, U$231, U$343, U$455, U$567, U$679, U$791, U$903, U$1015: #POCI#30
U$9, U$120, U$232, U$344, U$456, U$568, U$680, U$792, U$904, U$1016: #PICO#29
U$10, U$121, U$233, U$345, U$457, U$569, U$681, U$793, U$905, U$1017: 1836
U$11, U$42, U$150, U$208, U$262, U$320, U$374, U$432, U$486, U$544, U$598, U$656, U$710, U$768, U$822, U$880, U$934, U$992, U$1046, U$1104: #MEAS#1851
U$12, U$122, U$234, U$346, U$458, U$570, U$682, U$794, U$906, U$1018: #27#27
U$13, U$123, U$235, U$347, U$459, U$571, U$683, U$795, U$907, U$1019: #26#26
U$14, U$124, U$236, U$348, U$460, U$572, U$684, U$796, U$908, U$1020: TX1838
U$15, U$125, U$237, U$349, U$461, U$573, U$685, U$797, U$909, U$1021: RX1839
U$16, U$126, U$238, U$350, U$462, U$574, U$686, U$798, U$910, U$1022: PWR1837
U$17, U$127, U$239, U$351, U$463, U$575, U$687, U$799, U$911, U$1023: CHG1840
U$18, U$128, U$240, U$352, U$464, U$576, U$688, U$800, U$912, U$1024: #25#18
U$19, U$129, U$241, U$353, U$465, U$577, U$689, U$801, U$913, U$1025: #17#17
U$20, U$130, U$242, U$354, U$466, U$578, U$690, U$802, U$914, U$1026: #16#15
U$21, U$131, U$243, U$355, U$467, U$579, U$691, U$803, U$915, U$1027: #14#14
U$22, U$132, U$244, U$356, U$468, U$580, U$692, U$804, U$916, U$1028: #13#5
U$23, U$133, U$245, U$357, U$469, U$581, U$693, U$805, U$917, U$1029: #4#2
U$24, U$202, U$314, U$426, U$538, U$650, U$762, U$874, U$986, U$1098: #3#RX#0#4
U$25, U$199, U$311, U$423, U$535, U$647, U$759, U$871, U$983, U$1095: #3#RX#0#0
U$26, U$134, U$246, U$358, U$470, U$582, U$694, U$806, U$918, U$1030: #RESET#1842
U$27, U$135, U$247, U$359, U$471, U$583, U$695, U$807, U$919, U$1031: #BOOT#1841
U$28, U$46, U$136, U$154, U$248, U$266, U$360, U$378, U$472, U$490, U$584, U$602, U$696, U$714, U$808, U$826, U$920, U$938, U$1032, U$1050: #JTAG#1847
U$29, U$137, U$249, U$361, U$473, U$585, U$697, U$809, U$921, U$1033: #A0#1843
U$30, U$138, U$250, U$362, U$474, U$586, U$698, U$810, U$922, U$1034: #A3#1843
U$31, U$139, U$251, U$363, U$475, U$587, U$699, U$811, U$923, U$1035: #A6#1843
U$32, U$140, U$252, U$364, U$476, U$588, U$700, U$812, U$924, U$1036: #A7#1843
U$33, U$141, U$253, U$365, U$477, U$589, U$701, U$813, U$925, U$1037: #A4#1843
U$34, U$142, U$254, U$366, U$478, U$590, U$702, U$814, U$926, U$1038: #A5#1843
U$35, U$143, U$255, U$367, U$479, U$591, U$703, U$815, U$927, U$1039: #VIN#1843
U$36, U$37, U$144, U$145, U$256, U$257, U$368, U$369, U$480, U$481, U$592, U$593, U$704, U$705, U$816, U$817, U$928, U$929, U$1040, U$1041: #GND#1844
U$38, U$146, U$258, U$370, U$482, U$594, U$706, U$818, U$930, U$1042: #5V#1845
U$39, U$147, U$259, U$371, U$483, U$595, U$707, U$819, U$931, U$1043: #3#3V#1845
U$40, U$148, U$260, U$372, U$484, U$596, U$708, U$820, U$932, U$1044: ##RST##1845
U$41, U$149, U$261, U$373, U$485, U$597, U$709, U$821, U$933, U$1045: #REF#1846
U$43, U$86, U$151, U$186, U$263, U$298, U$375, U$410, U$487, U$522, U$599, U$634, U$711, U$746, U$823, U$858, U$935, U$970, U$1047, U$1082: #1849
U$44, U$88, U$152, U$187, U$264, U$299, U$376, U$411, U$488, U$523, U$600, U$635, U$712, U$747, U$824, U$859, U$936, U$971, U$1048, U$1083: #1850
U$45, U$153, U$265, U$377, U$489, U$601, U$713, U$825, U$937, U$1049: #BATT#1848
U$47, U$196, U$308, U$420, U$532, U$644, U$756, U$868, U$980, U$1092: #IOT#132321874
U$48, U$155, U$267, U$379, U$491, U$603, U$715, U$827, U$939, U$1051: ESP321855
U$49, U$214, U$326, U$438, U$550, U$662, U$774, U$886, U$998, U$1110: #LED_18#0
U$50, U$156, U$268, U$380, U$492, U$604, U$716, U$828, U$940, U$1052: #39#A3#321862
U$51, U$157, U$269, U$381, U$493, U$605, U$717, U$829, U$941, U$1053: #36#A0#321862
U$52, U$220, U$332, U$444, U$556, U$668, U$780, U$892, U$1004, U$1116: #33#A5#0
U$53, U$158, U$270, U$382, U$494, U$606, U$718, U$830, U$942, U$1054: #35#A7#321862
U$54, U$159, U$271, U$383, U$495, U$607, U$719, U$831, U$943, U$1055: #32#A4#32321865
U$55, U$160, U$272, U$384, U$496, U$608, U$720, U$832, U$944, U$1056: #34#A6#321862
U$56, U$161, U$273, U$385, U$497, U$609, U$721, U$833, U$945, U$1057: #VIN#321862
U$57, U$60, U$162, U$165, U$274, U$277, U$386, U$389, U$498, U$501, U$610, U$613, U$722, U$725, U$834, U$837, U$946, U$949, U$1058, U$1061: #GND#321863
U$58, U$163, U$275, U$387, U$499, U$611, U$723, U$835, U$947, U$1059: #5V#321864
U$59, U$164, U$276, U$388, U$500, U$612, U$724, U$836, U$948, U$1060: #3#3V#321864
U$61, U$166, U$278, U$390, U$502, U$614, U$726, U$838, U$950, U$1062: ##RESET##321864
U$62, U$167, U$279, U$391, U$503, U$615, U$727, U$839, U$951, U$1063: #IOREF#321865
U$63, U$204, U$316, U$428, U$540, U$652, U$764, U$876, U$988, U$1100: #5##CS##0
U$64, U$205, U$317, U$429, U$541, U$653, U$765, U$877, U$989, U$1101: #BYP#0
U$65, U$207, U$319, U$431, U$543, U$655, U$767, U$879, U$991, U$1103: RGB0
U$66, U$168, U$280, U$392, U$504, U$616, U$728, U$840, U$952, U$1064: #13#TCK#32321869
U$67, U$169, U$281, U$393, U$505, U$617, U$729, U$841, U$953, U$1065: #14#TMS#32321869
U$68, U$170, U$282, U$394, U$506, U$618, U$730, U$842, U$954, U$1066: #16#32321869
U$69, U$171, U$283, U$395, U$507, U$619, U$731, U$843, U$955, U$1067: #17#32321869
U$70, U$172, U$284, U$396, U$508, U$620, U$732, U$844, U$956, U$1068: #25#32321869
U$71, U$173, U$285, U$397, U$509, U$621, U$733, U$845, U$957, U$1069: #26#32321869
U$72, U$174, U$286, U$398, U$510, U$622, U$734, U$846, U$958, U$1070: #5##CS##32321869
U$73, U$175, U$287, U$399, U$511, U$623, U$735, U$847, U$959, U$1071: #23#PICO#321866
U$74, U$176, U$288, U$400, U$512, U$624, U$736, U$848, U$960, U$1072: #19#POCI#321866
U$75, U$177, U$289, U$401, U$513, U$625, U$737, U$849, U$961, U$1073: #18#SCK#32321869
U$76, U$178, U$290, U$402, U$514, U$626, U$738, U$850, U$962, U$1074: #21#SDA#32321869
U$77, U$179, U$291, U$403, U$515, U$627, U$739, U$851, U$963, U$1075: #22#SCL#32321869
U$78, U$180, U$292, U$404, U$516, U$628, U$740, U$852, U$964, U$1076: #27#32321869
U$79, U$181, U$293, U$405, U$517, U$629, U$741, U$853, U$965, U$1077: #GND#321866
U$80, U$182, U$294, U$406, U$518, U$630, U$742, U$854, U$966, U$1078: #3#3V#321866
U$81, U$206, U$318, U$430, U$542, U$654, U$766, U$878, U$990, U$1102: #SHLD#0
U$82, U$221, U$333, U$445, U$557, U$669, U$781, U$893, U$1005, U$1117: #I�C#0
U$83, U$183, U$295, U$407, U$519, U$631, U$743, U$855, U$967, U$1079: D#32321863
U$84, U$184, U$296, U$408, U$520, U$632, U$744, U$856, U$968, U$1080: D#32321862
U$85, U$185, U$297, U$409, U$521, U$633, U$745, U$857, U$969, U$1081: G32321864
U$89, U$222, U$334, U$446, U$558, U$670, U$782, U$894, U$1006, U$1118: #DO#0
U$90, U$188, U$300, U$412, U$524, U$636, U$748, U$860, U$972, U$1084: ##ALERT##1852
U$91, U$189, U$301, U$413, U$525, U$637, U$749, U$861, U$973, U$1085: #TMS#1854
U$92, U$190, U$302, U$414, U$526, U$638, U$750, U$862, U$974, U$1086: #TCK#1853
U$93, U$195, U$307, U$419, U$531, U$643, U$755, U$867, U$979, U$1091: ESP32321856
U$94, U$99, U$209, U$210, U$321, U$322, U$433, U$434, U$545, U$546, U$657, U$658, U$769, U$770, U$881, U$882, U$993, U$994, U$1105, U$1106: POLARITY_MARKING_CENTER_POSITIVE#JPG
U$96, U$97, U$191, U$192, U$303, U$304, U$415, U$416, U$527, U$528, U$639, U$640, U$751, U$752, U$863, U$864, U$975, U$976, U$1087, U$1088: INPUT_ONLY321867
U$98, U$193, U$305, U$417, U$529, U$641, U$753, U$865, U$977, U$1089: REDBOARD_LOGO
U$100, U$194, U$306, U$418, U$530, U$642, U$754, U$866, U$978, U$1090: #IOT#132321869
U$101, U$197, U$309, U$421, U$533, U$645, U$757, U$869, U$981, U$1093: 7#15V32321861
U$102, U$201, U$313, U$425, U$537, U$649, U$761, U$873, U$985, U$1097: #4##ALERT##0
U$103, U$198, U$310, U$422, U$534, U$646, U$758, U$870, U$982, U$1094: 3#3V_LOGIC_SHIELDS_ONLY132321876
U$104, U$200, U$312, U$424, U$536, U$648, U$760, U$872, U$984, U$1096: #1#TX#0#0
U$105, U$203, U$315, U$427, U$539, U$651, U$763, U$875, U$987, U$1099: #1#TX#0#2
U$106, U$211, U$323, U$435, U$547, U$659, U$771, U$883, U$995, U$1107: 7V#0
U$107, U$212, U$324, U$436, U$548, U$660, U$772, U$884, U$996, U$1108: 15V0
U$108, U$213, U$325, U$437, U$549, U$661, U$773, U$885, U$997, U$1109: #SD_DET#0
U$109, U$215, U$327, U$439, U$551, U$663, U$775, U$887, U$999, U$1111: #LED_TX#0
U$110, U$216, U$328, U$440, U$552, U$664, U$776, U$888, U$1000, U$1112: #LED_RX#0
U$111, U$217, U$329, U$441, U$553, U$665, U$777, U$889, U$1001, U$1113: #LED_PWR#0
U$112, U$218, U$330, U$442, U$554, U$666, U$778, U$890, U$1002, U$1114: #LED_CHG#0
U$113, U$219, U$331, U$443, U$555, U$667, U$779, U$891, U$1003, U$1115: GPIO20
U$114, U$223, U$335, U$447, U$559, U$671, U$783, U$895, U$1007, U$1119: #LED_DO#1
U$115, U$224, U$336, U$448, U$560, U$672, U$784, U$896, U$1008, U$1120: #NC#LED_DO#0

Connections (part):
3.3V: C2.1, C3.1, C7.1, C13.1, C14.1, C19.1, D2.A, D3.A, D5.A, D7.VCC, I2C.2, J5.3, J6.3A, J6.3B, J9.2, J9.4, J10.2, J10.4, J13.2, J15.4, R1.2, R23.2, U1.2, U2.16, U4.5
3.3V1: C24.1, C26.1, C27.1, C31.1, C37.1, C38.1, D8.A, D9.A, D13.A, D14.VCC, I2C1.2, J14.3A, J14.3B, J17.2, J17.4, J22.3, J23.2, J23.4, J27.2, J28.4, R37.2, R58.2, U7.16, U8.2, U10.5
3.3V2: C43.1, C45.1, C46.1, C50.1, C56.1, C57.1, D15.A, D16.A, D20.A, D21.VCC, I2C2.2, J31.3A, J31.3B, J32.2, J32.4, J37.3, J38.2, J38.4, J42.2, J43.4, R67.2, R88.2, U13.16, U14.2, U16.5
3.3V3: C62.1, C64.1, C65.1, C69.1, C75.1, C76.1, D22.A, D23.A, D27.A, D28.VCC, I2C3.2, J46.3A, J46.3B, J47.2, J47.4, J52.3, J53.2, J53.4, J57.2, J58.4, R97.2, R118.2, U19.16, U20.2, U22.5
3.3V4: C81.1, C83.1, C84.1, C88.1, C94.1, C95.1, D29.A, D30.A, D34.A, D35.VCC, I2C4.2, J61.3A, J61.3B, J62.2, J62.4, J67.3, J68.2, J68.4, J72.2, J73.4, R127.2, R148.2, U25.16, U26.2, U28.5
3.3V5: C100.1, C102.1, C103.1, C107.1, C113.1, C114.1, D36.A, D37.A, D41.A, D42.VCC, I2C5.2, J76.3A, J76.3B, J77.2, J77.4, J82.3, J83.2, J83.4, J87.2, J88.4, R157.2, R178.2, U31.16, U32.2, U34.5
3.3V6: C119.1, C121.1, C122.1, C126.1, C132.1, C133.1, D43.A, D44.A, D48.A, D49.VCC, I2C6.2, J91.3A, J91.3B, J92.2, J92.4, J97.3, J98.2, J98.4, J102.2, J103.4, R187.2, R208.2, U37.16, U38.2, U40.5
3.3V7: C138.1, C140.1, C141.1, C145.1, C151.1, C152.1, D50.A, D51.A, D55.A, D56.VCC, I2C7.2, J106.3A, J106.3B, J107.2, J107.4, J112.3, J113.2, J113.4, J117.2, J118.4, R217.2, R238.2, U43.16, U44.2, U46.5
3.3V8: C157.1, C159.1, C160.1, C164.1, C170.1, C171.1, D57.A, D58.A, D62.A, D63.VCC, I2C8.2, J121.3A, J121.3B, J122.2, J122.4, J127.3, J128.2, J128.4, J132.2, J133.4, R247.2, R268.2, U49.16, U50.2, U52.5
3.3V9: C176.1, C178.1, C179.1, C183.1, C189.1, C190.1, D64.A, D65.A, D69.A, D70.VCC, I2C9.2, J136.3A, J136.3B, J137.2, J137.4, J142.3, J143.2, J143.4, J147.2, J148.4, R277.2, R298.2, U55.16, U56.2, U58.5
5V: BYP.2, C12.1, C18.1, F1.2, J9.5, J10.5, U4.1, U4.3
5V1: BYP1.2, C32.1, C36.1, F2.2, J17.5, J23.5, U10.1, U10.3
5V2: BYP2.2, C51.1, C55.1, F3.2, J32.5, J38.5, U16.1, U16.3
5V3: BYP3.2, C70.1, C74.1, F4.2, J47.5, J53.5, U22.1, U22.3
5V4: BYP4.2, C89.1, C93.1, F5.2, J62.5, J68.5, U28.1, U28.3
5V5: BYP5.2, C108.1, C112.1, F6.2, J77.5, J83.5, U34.1, U34.3
5V6: BYP6.2, C127.1, C131.1, F7.2, J92.5, J98.5, U40.1, U40.3
5V7: BYP7.2, C146.1, C150.1, F8.2, J107.5, J113.5, U46.1, U46.3
5V8: BYP8.2, C165.1, C169.1, F9.2, J122.5, J128.5, U52.1, U52.3
5V9: BYP9.2, C184.1, C188.1, F10.2, J137.5, J143.5, U58.1, U58.3
5V_CHG: C15.1, D4.A, Q10.4, Q11.2, Q12.4, Q13.2, U5.4
5V_CHG1: C34.1, D12.A, Q23.4, Q24.2, Q25.4, Q26.2, U11.4
5V_CHG2: C53.1, D19.A, Q36.4, Q37.2, Q38.4, Q39.2, U17.4
5V_CHG3: C72.1, D26.A, Q49.4, Q50.2, Q51.4, Q52.2, U23.4
5V_CHG4: C91.1, D33.A, Q62.4, Q63.2, Q64.4, Q65.2, U29.4
5V_CHG5: C110.1, D40.A, Q75.4, Q76.2, Q77.4, Q78.2, U35.4
5V_CHG6: C129.1, D47.A, Q88.4, Q89.2, Q90.4, Q91.2, U41.4
5V_CHG7: C148.1, D54.A, Q101.4, Q102.2, Q103.4, Q104.2, U47.4
5V_CHG8: C167.1, D61.A, Q114.4, Q115.2, Q116.4, Q117.2, U53.4
5V_CHG9: C186.1, D68.A, Q127.4, Q128.2, Q129.4, Q130.2, U59.4
5V_EXT: C10.+, C11.1, Q6.1, Q7.3, Q12.1, Q13.3, R10.2, R12.1, U3.2, U3.4
5V_EXT1: C28.+, C29.1, Q19.1, Q20.3, Q25.1, Q26.3, R42.2, R47.1, U9.2, U9.4
5V_EXT2: C47.+, C48.1, Q32.1, Q33.3, Q38.1, Q39.3, R72.2, R77.1, U15.2, U15.4
5V_EXT3: C66.+, C67.1, Q45.1, Q46.3, Q51.1, Q52.3, R102.2, R107.1, U21.2, U21.4
5V_EXT4: C85.+, C86.1, Q58.1, Q59.3, Q64.1, Q65.3, R132.2, R137.1, U27.2, U27.4
5V_EXT5: C104.+, C105.1, Q71.1, Q72.3, Q77.1, Q78.3, R162.2, R167.1, U33.2, U33.4
5V_EXT6: C123.+, C124.1, Q84.1, Q85.3, Q90.1, Q91.3, R192.2, R197.1, U39.2, U39.4
5V_EXT7: C142.+, C143.1, Q97.1, Q98.3, Q103.1, Q104.3, R222.2, R227.1, U45.2, U45.4
5V_EXT8: C161.+, C162.1, Q110.1, Q111.3, Q116.1, Q117.3, R252.2, R257.1, U51.2, U51.4
5V_EXT9: C180.+, C181.1, Q123.1, Q124.3, Q129.1, Q130.3, R282.2, R287.1, U57.2, U57.4
5V_MEAS: MEAS.1, MEAS.3, Q4.4, Q5.2, Q6.4, Q7.2, Q8.4, Q9.2
5V_MEAS1: MEAS1.1, MEAS1.3, Q15.4, Q16.2, Q19.4, Q20.2, Q21.4, Q22.2
5V_MEAS2: MEAS2.1, MEAS2.3, Q28.4, Q29.2, Q32.4, Q33.2, Q34.4, Q35.2
5V_MEAS3: MEAS3.1, MEAS3.3, Q41.4, Q42.2, Q45.4, Q46.2, Q47.4, Q48.2
5V_MEAS4: MEAS4.1, MEAS4.3, Q54.4, Q55.2, Q58.4, Q59.2, Q60.4, Q61.2
5V_MEAS5: MEAS5.1, MEAS5.3, Q67.4, Q68.2, Q71.4, Q72.2, Q73.4, Q74.2
5V_MEAS6: MEAS6.1, MEAS6.3, Q80.4, Q81.2, Q84.4, Q85.2, Q86.4, Q87.2
5V_MEAS7: MEAS7.1, MEAS7.3, Q93.4, Q94.2, Q97.4, Q98.2, Q99.4, Q100.2
5V_MEAS8: MEAS8.1, MEAS8.3, Q106.4, Q107.2, Q110.4, Q111.2, Q112.4, Q113.2
5V_MEAS9: MEAS9.1, MEAS9.3, Q119.4, Q120.2, Q123.4, Q124.2, Q125.4, Q126.2
!DTR!: Q1.4, R6.1, U2.13
!DTR!1: Q14.4, R36.1, U7.13
!DTR!2: Q27.4, R66.1, U13.13
!DTR!3: Q40.4, R96.1, U19.13
!DTR!4: Q53.4, R126.1, U25.13
!DTR!5: Q66.4, R156.1, U31.13
!DTR!6: Q79.4, R186.1, U37.13
!DTR!7: Q92.4, R216.1, U43.13
!DTR!8: Q105.4, R246.1, U49.13
!DTR!9: Q118.4, R276.1, U55.13
!GAUGE_ALERT!: !ALERT!.1, R23.1, U6.5
!GAUGE_ALERT!1: !ALERT!1.1, R58.1, U12.5
!GAUGE_ALERT!2: !ALERT!2.1, R88.1, U18.5
!GAUGE_ALERT!3: !ALERT!3.1, R118.1, U24.5
!GAUGE_ALERT!4: !ALERT!4.1, R148.1, U30.5
!GAUGE_ALERT!5: !ALERT!5.1, R178.1, U36.5
!GAUGE_ALERT!6: !ALERT!6.1, R208.1, U42.5
!GAUGE_ALERT!7: !ALERT!7.1, R238.1, U48.5
!GAUGE_ALERT!8: !ALERT!8.1, R268.1, U54.5
!GAUGE_ALERT!9: !ALERT!9.1, R298.1, U60.5
!RTS!: Q1.1, R7.1, U2.14
!RTS!1: Q14.1, R35.1, U7.14
!RTS!2: Q27.1, R65.1, U13.14
!RTS!3: Q40.1, R95.1, U19.14
!RTS!4: Q53.1, R125.1, U25.14
!RTS!5: Q66.1, R155.1, U31.14
!RTS!6: Q79.1, R185.1, U37.14
!RTS!7: Q92.1, R215.1, U43.14
!RTS!8: Q105.1, R245.1, U49.14
!RTS!9: Q118.1, R275.1, U55.14
CC1: J2.A5, R3.2
CC2: J2.B5, R2.2
CC3: J20.B5, R33.2
CC4: J20.A5, R34.2
CC5: J35.B5, R63.2
CC6: J35.A5, R64.2
CC7: J50.B5, R93.2
CC8: J50.A5, R94.2
CC9: J65.B5, R123.2
CC10: J65.A5, R124.2
CC11: J80.B5, R153.2
CC12: J80.A5, R154.2
CC13: J95.B5, R183.2
CC14: J95.A5, R184.2
CC15: J110.B5, R213.2
CC16: J110.A5, R214.2
CC17: J125.B5, R243.2
CC18: J125.A5, R244.2
CC19: J140.B5, R273.2
CC20: J140.A5, R274.2
D+: J2.A6, J2.B6, J3.D+, U2.5
D+1: J20.A6, J20.B6, J21.D+, U7.5
D+2: J35.A6, J35.B6, J36.D+, U13.5
D+3: J50.A6, J50.B6, J51.D+, U19.5
D+4: J65.A6, J65.B6, J66.D+, U25.5
D+5: J80.A6, J80.B6, J81.D+, U31.5
D+6: J95.A6, J95.B6, J96.D+, U37.5
D+7: J110.A6, J110.B6, J111.D+, U43.5
D+8: J125.A6, J125.B6, J126.D+, U49.5
D+9: J140.A6, J140.B6, J141.D+, U55.5
D-: J2.A7, J2.B7, J3.D-, U2.6
D-1: J20.A7, J20.B7, J21.D-, U7.6
D-2: J35.A7, J35.B7, J36.D-, U13.6
D-3: J50.A7, J50.B7, J51.D-, U19.6
D-4: J65.A7, J65.B7, J66.D-, U25.6
D-5: J80.A7, J80.B7, J81.D-, U31.6
D-6: J95.A7, J95.B7, J96.D-, U37.6
D-7: J110.A7, J110.B7, J111.D-, U43.6
D-8: J125.A7, J125.B7, J126.D-, U49.6
D-9: J140.A7, J140.B7, J141.D-, U55.6
ESP32_0: DOOT.3, DOOT.4, Q1.3, U1.25
ESP32_1: DOOT1.3, DOOT1.4, Q14.3, U8.25
ESP32_2: DOOT2.3, DOOT2.4, Q27.3, U14.25
ESP32_3: DOOT3.3, DOOT3.4, Q40.3, U20.25
ESP32_4: DOOT4.3, DOOT4.4, Q53.3, U26.25
ESP32_5: DOOT5.3, DOOT5.4, Q66.3, U32.25
ESP32_6: DOOT6.3, DOOT6.4, Q79.3, U38.25
ESP32_7: DOOT7.3, DOOT7.4, Q92.3, U44.25
ESP32_8: DOOT8.3, DOOT8.4, Q105.3, U50.25
ESP32_9: DOOT9.3, DOOT9.4, Q118.3, U56.25
ESP32_ADC0: J11.6, J12.6, U1.4
ESP32_ADC1: J19.6, J24.6, U8.4
ESP32_ADC2: J19.5, J24.5, U8.5
ESP32_ADC3: J11.5, J12.5, U1.5
ESP32_ADC4: J11.2, J12.2, U1.8
ESP32_ADC5: J11.1, J12.1, U1.9
ESP32_ADC6: J11.4, J12.4, U1.6
ESP32_ADC7: J11.3, J12.3, U1.7
ESP32_ADC8: J19.4, J24.4, U8.6
ESP32_ADC9: J19.3, J24.3, U8.7
ESP32_ADC10: J19.1, J24.1, U8.9
ESP32_ADC11: J19.2, J24.2, U8.8
ESP32_ADC12: J34.6, J39.6, U14.4
ESP32_ADC13: J34.5, J39.5, U14.5
ESP32_ADC14: J34.4, J39.4, U14.6
ESP32_ADC15: J34.3, J39.3, U14.7
ESP32_ADC16: J34.1, J39.1, U14.9
ESP32_ADC17: J34.2, J39.2, U14.8
ESP32_ADC18: J49.6, J54.6, U20.4
ESP32_ADC19: J49.5, J54.5, U20.5
ESP32_ADC20: J49.4, J54.4, U20.6
ESP32_ADC21: J49.3, J54.3, U20.7
ESP32_ADC22: J49.1, J54.1, U20.9
ESP32_ADC23: J49.2, J54.2, U20.8
ESP32_ADC24: J64.6, J69.6, U26.4
ESP32_ADC25: J64.5, J69.5, U26.5
ESP32_ADC26: J64.4, J69.4, U26.6
ESP32_ADC27: J64.3, J69.3, U26.7
ESP32_ADC28: J64.1, J69.1, U26.9
ESP32_ADC29: J64.2, J69.2, U26.8
ESP32_ADC30: J79.6, J84.6, U32.4
ESP32_ADC31: J79.5, J84.5, U32.5
ESP32_ADC32: J79.4, J84.4, U32.6
ESP32_ADC33: J79.3, J84.3, U32.7
ESP32_ADC34: J79.1, J84.1, U32.9
ESP32_ADC35: J79.2, J84.2, U32.8
ESP32_ADC36: J94.6, J99.6, U38.4
ESP32_ADC37: J94.5, J99.5, U38.5
ESP32_ADC38: J94.4, J99.4, U38.6
ESP32_ADC39: J94.3, J99.3, U38.7
ESP32_ADC40: J94.1, J99.1, U38.9
ESP32_ADC41: J94.2, J99.2, U38.8
ESP32_ADC42: J109.6, J114.6, U44.4
ESP32_ADC43: J109.5, J114.5, U44.5
ESP32_ADC44: J109.4, J114.4, U44.6
ESP32_ADC45: J109.3, J114.3, U44.7
ESP32_ADC46: J109.1, J114.1, U44.9
ESP32_ADC47: J109.2, J114.2, U44.8
ESP32_ADC48: J124.6, J129.6, U50.4
ESP32_ADC49: J124.5, J129.5, U50.5
ESP32_ADC50: J124.4, J129.4, U50.6
ESP32_ADC51: J124.3, J129.3, U50.7
ESP32_ADC52: J124.1, J129.1, U50.9
ESP32_ADC53: J124.2, J129.2, U50.8
ESP32_ADC54: J139.6, J144.6, U56.4
ESP32_ADC55: J139.5, J144.5, U56.5
ESP32_ADC56: J139.4, J144.4, U56.6
ESP32_ADC57: J139.3, J144.3, U56.7
ESP32_ADC58: J139.1, J144.1, U56.9
ESP32_ADC59: J139.2, J144.2, U56.8
ESP32_EN: C1.1, J9.3, J10.3, Q1.6, R1.1, S1.3, S1.4, U1.3
ESP32_EN1: C25.1, J17.3, J23.3, Q14.6, R37.1, S2.3, S2.4, U8.3
ESP32_EN2: C44.1, J32.3, J38.3, Q27.6, R67.1, S3.3, S3.4, U14.3
ESP32_EN3: C63.1, J47.3, J53.3, Q40.6, R97.1, S4.3, S4.4, U20.3
ESP32_EN4: C82.1, J62.3, J68.3, Q53.6, R127.1, S5.3, S5.4, U26.3
ESP32_EN5: C101.1, J77.3, J83.3, Q66.6, R157.1, S6.3, S6.4, U32.3
ESP32_EN6: C120.1, J92.3, J98.3, Q79.6, R187.1, S7.3, S7.4, U38.3
ESP32_EN7: C139.1, J107.3, J113.3, Q92.6, R217.1, S8.3, S8.4, U44.3
ESP32_EN8: C158.1, J122.3, J128.3, Q105.6, R247.1, S9.3, S9.4, U50.3
ESP32_EN9: C177.1, J137.3, J143.3, Q118.6, R277.1, S10.3, S10.4, U56.3
ESP32_GPIO1: D14.DI, U8.24
ESP32_GPIO2: D7.DI, U1.24
ESP32_GPIO3: !ALERT!1.2, J18.3, J25.3, U8.26
ESP32_GPIO4: !ALERT!.2, J7.3, J8.3, U1.26
ESP32_GPIO5: J18.7, J25.7, U8.28
ESP32_GPIO5_!CS!: J5.8, J6.8A, J6.8B, J15.2, U1.29
ESP32_GPIO5_!CS!1: J14.8A, J14.8B, J22.8, J28.2, U8.29
ESP32_GPIO5_!CS!2: J31.8A, J31.8B, J37.8, J43.2, U14.29
ESP32_GPIO5_!CS!3: J46.8A, J46.8B, J52.8, J58.2, U20.29
ESP32_GPIO5_!CS!4: J61.8A, J61.8B, J67.8, J73.2, U26.29
ESP32_GPIO5_!CS!5: J76.8A, J76.8B, J82.8, J88.2, U32.29
ESP32_GPIO5_!CS!6: J91.8A, J91.8B, J97.8, J103.2, U38.29
ESP32_GPIO5_!CS!7: J106.8A, J106.8B, J112.8, J118.2, U44.29
ESP32_GPIO5_!CS!8: J121.8A, J121.8B, J127.8, J133.2, U50.29
ESP32_GPIO5_!CS!9: J136.8A, J136.8B, J142.8, J148.2, U56.29
ESP32_GPIO6: J18.8, J25.8, U8.10
ESP32_GPIO7: J14.10A, J14.10B, J22.10, U8.11
ESP32_GPIO8: J14.9A, J14.9B, J22.9, U8.12
ESP32_GPIO9: J18.6, J25.6, SD_DET1.2, U8.27
ESP32_GPIO10: D21.DI, U14.24
ESP32_GPIO11: !ALERT!2.2, J33.3, J40.3, U14.26
ESP32_GPIO12: J33.7, J40.7, U14.28
ESP32_GPIO12_TDI: J4.8, TP1.1, U1.14
ESP32_GPIO12_TDI1: J26.8, TP2.1, U8.14
ESP32_GPIO12_TDI2: J41.8, TP3.1, U14.14
ESP32_GPIO12_TDI3: J56.8, TP4.1, U20.14
ESP32_GPIO12_TDI4: J71.8, TP5.1, U26.14
ESP32_GPIO12_TDI5: J86.8, TP6.1, U32.14
ESP32_GPIO12_TDI6: J101.8, TP7.1, U38.14
ESP32_GPIO12_TDI7: J116.8, TP8.1, U44.14
ESP32_GPIO12_TDI8: J131.8, TP9.1, U50.14
ESP32_GPIO12_TDI9: J146.8, TP10.1, U56.14
ESP32_GPIO13: J33.8, J40.8, U14.10
ESP32_GPIO13_HDR: J7.4, J8.4, TCK.2
ESP32_GPIO13_HDR1: J18.4, J25.4, TCK1.2
ESP32_GPIO13_HDR2: J33.4, J40.4, TCK2.2
ESP32_GPIO13_HDR3: J48.4, J55.4, TCK3.2
ESP32_GPIO13_HDR4: J63.4, J70.4, TCK4.2
ESP32_GPIO13_HDR5: J78.4, J85.4, TCK5.2
ESP32_GPIO13_HDR6: J93.4, J100.4, TCK6.2
ESP32_GPIO13_HDR7: J108.4, J115.4, TCK7.2
ESP32_GPIO13_HDR8: J123.4, J130.4, TCK8.2
ESP32_GPIO13_HDR9: J138.4, J145.4, TCK9.2
ESP32_GPIO13_TCK: J4.4, TCK.1, U1.16
ESP32_GPIO13_TCK1: J26.4, TCK1.1, U8.16
ESP32_GPIO13_TCK2: J41.4, TCK2.1, U14.16
ESP32_GPIO13_TCK3: J56.4, TCK3.1, U20.16
ESP32_GPIO13_TCK4: J71.4, TCK4.1, U26.16
ESP32_GPIO13_TCK5: J86.4, TCK5.1, U32.16
ESP32_GPIO13_TCK6: J101.4, TCK6.1, U38.16
ESP32_GPIO13_TCK7: J116.4, TCK7.1, U44.16
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

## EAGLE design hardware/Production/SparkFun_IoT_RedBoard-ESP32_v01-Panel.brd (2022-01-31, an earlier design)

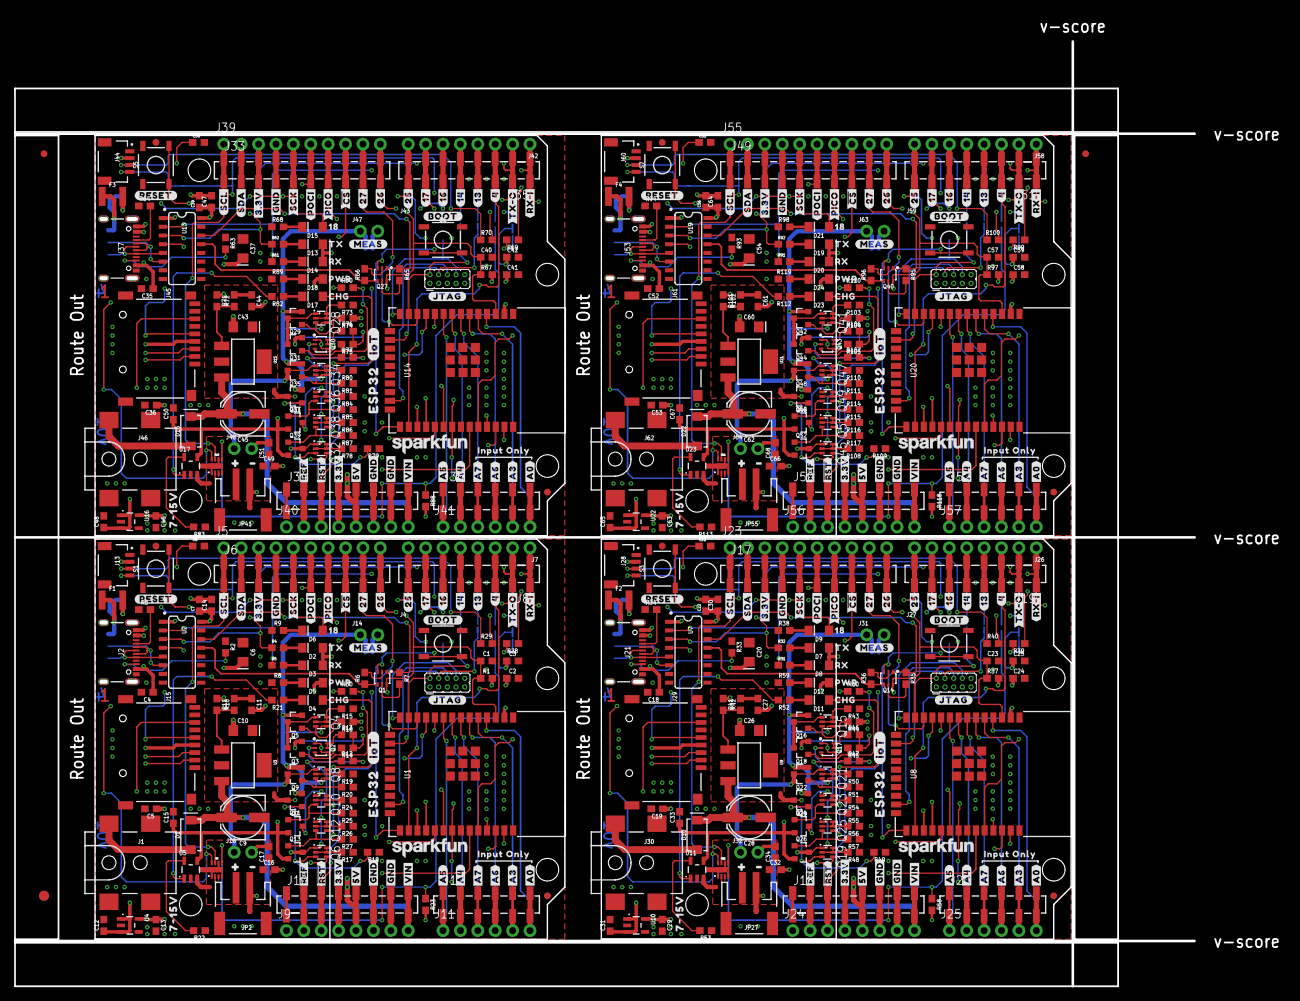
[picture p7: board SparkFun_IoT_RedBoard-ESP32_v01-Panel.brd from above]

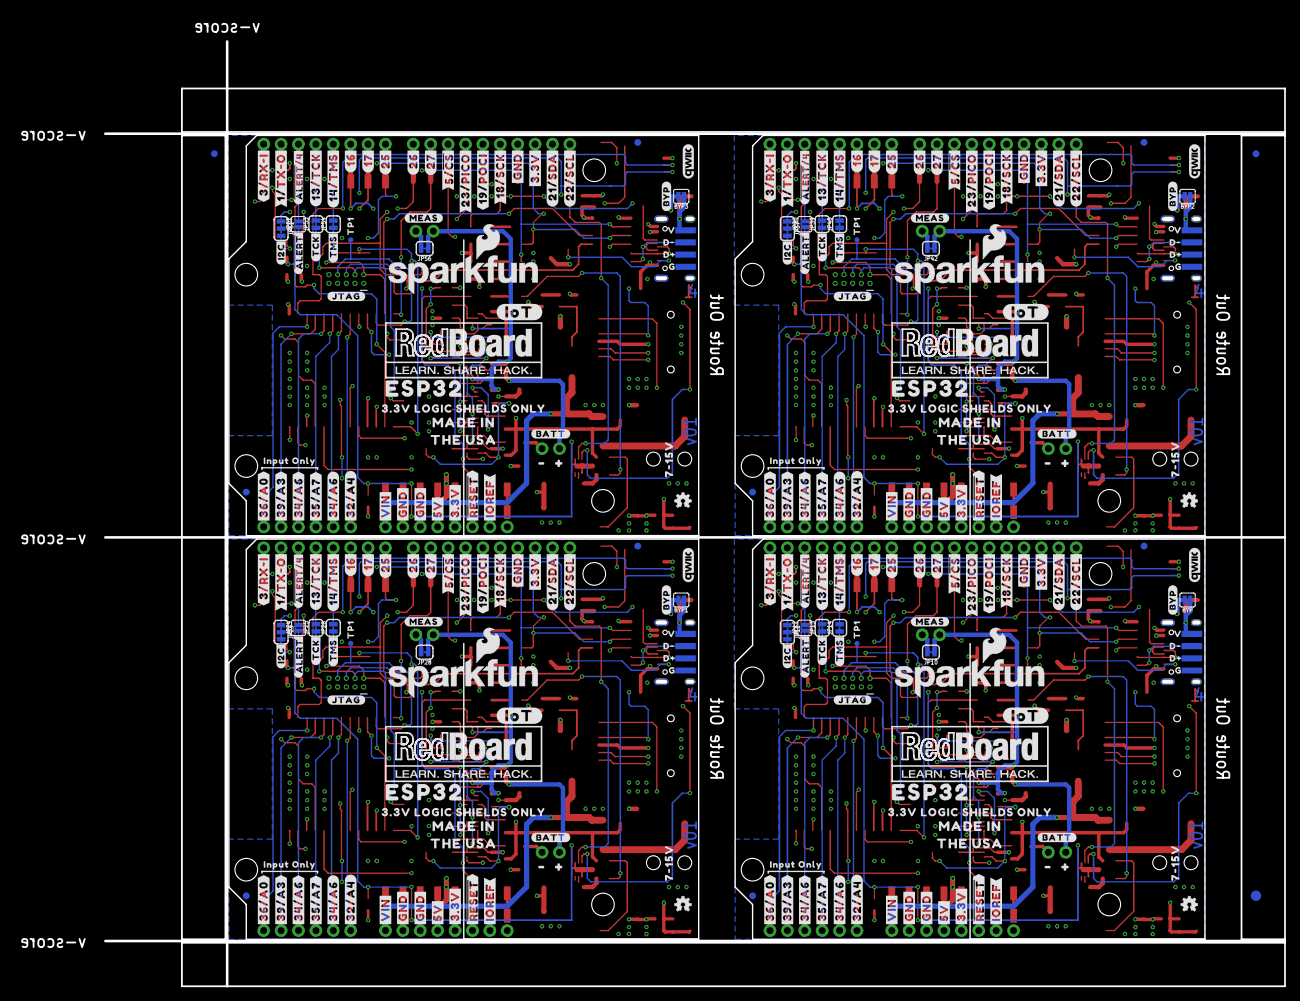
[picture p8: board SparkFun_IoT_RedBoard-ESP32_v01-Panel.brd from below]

Board: 4 copper layers, 172.2 x 137.9 mm, 850 parts (271 on the bottom side), 296 nets.

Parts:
BYP, BYP1, BYP2, BYP3: JUMPER-SMT_2_NO_SILK; SMT-JUMPER_2_NO_SILK
C1, C2, C4, C5, C7, C11, C12, C13, C17, C18, C19, C22, C23, C24, C27, C29, C31, C34, C35, C36, C39, C40, C41, C44, C46, C48, C51, C52, C53, C56, C57, C58, C61, C63, C65, C68: 0.1uF; 0603
C3, C14, C25, C30, C42, C47, C59, C64: 10uF; 0603
C6, C10, C20, C26, C37, C43, C54, C60: 10uF; EIA3216
C8, C21, C38, C55: 10nF; 0603
C9, C28, C45, C62: 47uF; PANASONIC_D
C15, C16, C32, C33, C49, C50, C66, C67: 4.7uF; 0603
D1, D10, D16, D22: 1A/40V/500mV; SMA-DIODE
D2, D7, D13, D19: GREEN; LED-1206-HIDDENSILK
D3, D8, D14, D20: YELLOW; LED-1206-HIDDENSILK
D4, D11, D17, D23: RED; LED-1206-HIDDENSILK
D5, D12, D18, D24: PWR; LED-1206-HIDDENSILK
D6, D9, D15, D21: BLUE; LED-1206-HIDDENSILK
E$1, E$2, E$3, E$4: FIDUCIAL-1X2
E$5, E$6: FIDUCIAL-1.5X3
F1, F2, F3, F4: 6V/2A; 1210
J1, J30, J46, J62: 5.5x2.1mm Barrel; POWER_JACK_SMD
J2, J21, J37, J53: USB C; USB-C-16P-2LAYER-PADS
J3, J22, J38, J54: USB_SOLDER_PADS; USB-SOLDER-PADS
J4, J27, J43, J59: 2X5_PTH_SILK_.05
J5, J23, J39, J55: M10NO_SILK; 1X10_NO_SILK
J6, J17, J33, J49: 1X10_SMD_COMBINED
J7, J9, J24, J26, J40, J42, J56, J58: 1X08_NO_SILK
J8, J10, J18, J19, J34, J35, J50, J51: 1X08_SMD_COMBINED
J11, J25, J41, J57: 1X06_NO_SILK
J12, J20, J36, J52: 1X06_SMD_STRAIGHT_COMBO
J13, J28, J44, J60: QWIIC_RIGHT_ANGLE; JST04_1MM_RA
J14, J16, J31, J32, J47, J48, J63, J64: 1X02_NO_SILK
J15, J29, J45, J61: MICRO-SD-PUSH-PUSH-EXT-PIN; MICROSD-EXTERNALPIN
JP1, JP7, JP8, JP9, JP19, JP20, JP21, JP22, JP33, JP34, JP35, JP36, JP47, JP48, JP49, JP50: FIDUCIAL1X2; FIDUCIAL-1X2
JP2, JP27, JP41, JP55: LiPo; JST-2-SMD
JP3, JP4, JP5, JP6, JP15, JP16, JP17, JP18, JP29, JP30, JP31, JP32, JP43, JP44, JP45, JP46: STAND-OFF
JP10, JP13, JP14, JP25, JP26, JP28, JP39, JP40, JP42, JP53, JP54, JP56: JUMPER-SMT_2_NC_TRACE_SILK; SMT-JUMPER_2_NC_TRACE_SILK
JP11, JP23, JP37, JP51: JUMPER-SMT_3_2-NC_TRACE_SILK; SMT-JUMPER_3_2-NC_TRACE_SILK
JP12, JP24, JP38, JP52: JUMPER-SMT_2_NO_SILK; SMT-JUMPER_2_NO_SILK
LOGO1, LOGO4, LOGO9, LOGO13: SFE_LOGO_NAME.1_INCH; SFE_LOGO_NAME_.1
LOGO2, LOGO5, LOGO10, LOGO14: QWIIC_LOGO_5MM; QWIIC_5MM
LOGO3, LOGO7, LOGO11, LOGO15: OSHW-LOGOMINI; OSHW-LOGO-MINI
LOGO6, LOGO8, LOGO12, LOGO16: SFE_LOGO_NAME_FLAME.2_INCH; SFE_LOGO_NAME_FLAME_.2
Q1, Q14, Q27, Q40: MBT3904DW1T1; SC70-6
Q2, Q17, Q30, Q43: SC70-6
Q3, Q5, Q7, Q9, Q11, Q13, Q16, Q18, Q20, Q22, Q24, Q26, Q29, Q31, Q33, Q35, Q37, Q39, Q42, Q44, Q46, Q48, Q50, Q52: 20V/4.2A/52mΩ/1.4W; SOT23-3
Q4, Q6, Q8, Q10, Q12, Q15, Q19, Q21, Q23, Q25, Q28, Q32, Q34, Q36, Q38, Q41, Q45, Q47, Q49, Q51: SOT363_PHILIPS
R1, R6, R7, R8, R12, R13, R14, R15, R17, R19, R23, R24, R26, R35, R36, R37, R43, R45, R46, R47, R48, R50, R54, R56, R58, R59, R65, R66, R67, R73, R75, R76, R77, R78, R80, R84, R86, R88, R89, R95, R96, R97, R103, R105, R106, R107, R108, R110, R114, R116, R118, R119: 10k; 0603
R2, R3, R33, R34, R63, R64, R93, R94: 5.1k; 0603
R4, R5, R9, R31, R32, R38, R61, R62, R68, R91, R92, R98: 4.7k; 0603
R10, R42, R72, R102: 240; 0603
R11, R41, R71, R101: 715; 0603
R16, R18, R20, R25, R27, R44, R49, R51, R55, R57, R74, R79, R81, R85, R87, R104, R109, R111, R115, R117: 47k; 0603
R21, R52, R82, R112: 1k; 0603
R22, R53, R83, R113: 2.0k; 0603
R28, R29, R39, R40, R69, R70, R99, R100: 2.2k; 0603
R30, R60, R90, R120: 100; 0603
S1, S3, S5, S7: Reset; TACTILE_SWITCH_SMD_5.2MM
S2, S4, S6, S8: GPIO0; TACTILE_SWITCH_SMD_5.2MM
TP1, TP2, TP3, TP4: TEST-POINT3; PAD.03X.03
U1, U8, U14, U20: ESP-WROOM-3232D-NARROW; ESP-WROOM-32D-NARROW
U2, U7, U13, U19: CH340C; SO016
U3, U9, U15, U21: LM1117; SOT223
U4, U10, U16, U22: 3.3V; SOT23-5
U5, U11, U17, U23: MCP73831; SOT23-5
U6, U12, U18, U24: MAX17048; DFN-8
U$1, U$87, U$201, U$301: V323252
U$2, U$3, U$202, U$302: #SCL#34
U$4, U$102, U$203, U$303: #SDA#33
U$5, U$104, U$204, U$304: #3#3V#33
U$6, U$105, U$205, U$305: #GND#32
U$7, U$106, U$206, U$306: #SCK#31
U$8, U$107, U$207, U$307: #POCI#30
U$9, U$108, U$208, U$308: #PICO#29
U$10, U$109, U$209, U$309: 1836
U$11, U$110, U$210, U$310: ##CS##28
U$12, U$111, U$211, U$311: #27#27
U$13, U$112, U$212, U$312: #26#26
U$14, U$113, U$213, U$313: TX1838
U$15, U$114, U$214, U$314: RX1839
U$16, U$115, U$215, U$315: PWR1837
U$17, U$116, U$216, U$316: CHG1840
U$18, U$117, U$217, U$317: #25#18
U$19, U$118, U$218, U$318: #17#17
U$20, U$119, U$219, U$319: #16#15
U$21, U$120, U$220, U$320: #14#14
U$22, U$121, U$221, U$321: #13#5
U$23, U$122, U$222, U$322: #4#2
U$24, U$123, U$223, U$323: #TX#O#0
U$25, U$124, U$224, U$324: #RX#I#1
U$26, U$125, U$225, U$325: #RESET#1842
U$27, U$126, U$226, U$326: #BOOT#1841
U$28, U$46, U$127, U$145, U$227, U$245, U$327, U$345: #JTAG#1847
U$29, U$128, U$228, U$328: #A0#1843
U$30, U$129, U$229, U$329: #A3#1843
U$31, U$130, U$230, U$330: #A6#1843
U$32, U$131, U$231, U$331: #A7#1843
U$33, U$132, U$232, U$332: #A4#1843
U$34, U$133, U$233, U$333: #A5#1843
U$35, U$134, U$234, U$334: #VIN#1843
U$36, U$37, U$135, U$136, U$235, U$236, U$335, U$336: #GND#1844
U$38, U$137, U$237, U$337: #5V#1845
U$39, U$138, U$238, U$338: #3#3V#1845
U$40, U$139, U$239, U$339: ##RST##1845
U$41, U$140, U$240, U$340: #REF#1846
U$42, U$81, U$141, U$178, U$241, U$278, U$341, U$378: #MEAS#1851
U$43, U$86, U$142, U$183, U$242, U$283, U$342, U$383: #1849
U$44, U$88, U$143, U$184, U$243, U$284, U$343, U$384: #1850
U$45, U$144, U$244, U$344: #BATT#1848
U$47, U$196, U$296, U$396: #IOT#132321874
U$48, U$146, U$246, U$346: ESP321855
U$49, U$101, U$147, U$199, U$247, U$299, U$347, U$399: 7#15V32321861
U$50, U$148, U$248, U$348: #39#A3#321862
U$51, U$149, U$249, U$349: #36#A0#321862
U$52, U$150, U$250, U$350: #34#A6#32321865
U$53, U$151, U$251, U$351: #35#A7#321862
U$54, U$152, U$252, U$352: #32#A4#32321865
U$55, U$153, U$253, U$353: #34#A6#321862
U$56, U$154, U$254, U$354: #VIN#321862
U$57, U$60, U$155, U$158, U$255, U$258, U$355, U$358: #GND#321863
U$58, U$156, U$256, U$356: #5V#321864
U$59, U$157, U$257, U$357: #3#3V#321864
U$61, U$159, U$259, U$359: ##RESET##321864
U$62, U$160, U$260, U$360: #IOREF#321865
U$63, U$161, U$261, U$361: #3#RX#I#32321869
U$64, U$162, U$262, U$362: #1#TX#O#32321869
U$65, U$191, U$291, U$391: ##ALERT##4#321866
U$66, U$163, U$263, U$363: #13#TCK#32321869
U$67, U$164, U$264, U$364: #14#TMS#32321869
U$68, U$165, U$265, U$365: #16#32321869
U$69, U$166, U$266, U$366: #17#32321869
U$70, U$167, U$267, U$367: #25#32321869
U$71, U$168, U$268, U$368: #26#32321869
U$72, U$169, U$269, U$369: #5##CS##32321869
U$73, U$170, U$270, U$370: #23#PICO#321866
U$74, U$171, U$271, U$371: #19#POCI#321866
U$75, U$172, U$272, U$372: #18#SCK#32321869
U$76, U$173, U$273, U$373: #21#SDA#32321869
U$77, U$174, U$274, U$374: #22#SCL#32321869
U$78, U$175, U$275, U$375: #27#32321869
U$79, U$176, U$276, U$376: #GND#321866
U$80, U$177, U$277, U$377: #3#3V#321866
U$82, U$179, U$279, U$379: #BYP#35
U$83, U$180, U$280, U$380: D#32321863
U$84, U$181, U$281, U$381: D#32321862
U$85, U$182, U$282, U$382: G32321864
U$89, U$185, U$285, U$385: #I2C#1855
U$90, U$186, U$286, U$386: ##ALERT##1852
U$91, U$187, U$287, U$387: #TMS#1854
U$92, U$188, U$288, U$388: #TCK#1853
U$93, U$195, U$295, U$395: ESP32321856
U$94, U$197, U$297, U$397: MADE_IN32321857
U$95, U$192, U$292, U$392: TP1321868
U$96, U$97, U$189, U$190, U$289, U$290, U$389, U$390: INPUT_ONLY321867
U$98, U$193, U$293, U$393: REDBOARD_LOGO
U$99, U$198, U$298, U$398: THE_USA32321858
U$100, U$194, U$294, U$394: #IOT#132321869
U$103, U$200, U$300, U$400: 3#3V_LOGIC_SHIELDS_ONLY132321876

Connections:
3.3V: C2.1, C3.1, C7.1, C13.1, C14.1, D2.A, D3.A, D5.A, J5.3, J6.3A, J6.3B, J9.2, J9.4, J10.2, J10.4, J13.2, J15.4, JP11.2, R1.2, R23.2, U1.2, U2.16, U4.5
3.3V1: C22.1, C24.1, C25.1, C29.1, C30.1, D7.A, D8.A, D12.A, J17.3A, J17.3B, J18.2, J18.4, J23.3, J24.2, J24.4, J28.2, J29.4, JP23.2, R37.2, R58.2, U7.16, U8.2, U10.5
3.3V2: C39.1, C41.1, C42.1, C46.1, C47.1, D13.A, D14.A, D18.A, J33.3A, J33.3B, J34.2, J34.4, J39.3, J40.2, J40.4, J44.2, J45.4, JP37.2, R67.2, R88.2, U13.16, U14.2, U16.5
3.3V3: C56.1, C58.1, C59.1, C63.1, C64.1, D19.A, D20.A, D24.A, J49.3A, J49.3B, J50.2, J50.4, J55.3, J56.2, J56.4, J60.2, J61.4, JP51.2, R97.2, R118.2, U19.16, U20.2, U22.5
5V: C12.1, J9.5, J10.5, J14.2, JP10.2, U4.1, U4.3
5V1: C31.1, J18.5, J24.5, J31.2, JP28.2, U10.1, U10.3
5V2: C48.1, J34.5, J40.5, J47.2, JP42.2, U16.1, U16.3
5V3: C65.1, J50.5, J56.5, J63.2, JP56.2, U22.1, U22.3
5V_CHG: C15.1, D4.A, Q10.4, Q11.2, Q12.4, Q13.2, U5.4
5V_CHG1: C33.1, D11.A, Q23.4, Q24.2, Q25.4, Q26.2, U11.4
5V_CHG2: C50.1, D17.A, Q36.4, Q37.2, Q38.4, Q39.2, U17.4
5V_CHG3: C67.1, D23.A, Q49.4, Q50.2, Q51.4, Q52.2, U23.4
5V_EXT: C10.+, C11.1, Q6.1, Q7.3, Q12.1, Q13.3, R10.2, R12.1, U3.2, U3.4
5V_EXT1: C26.+, C27.1, Q19.1, Q20.3, Q25.1, Q26.3, R42.2, R47.1, U9.2, U9.4
5V_EXT2: C43.+, C44.1, Q32.1, Q33.3, Q38.1, Q39.3, R72.2, R77.1, U15.2, U15.4
5V_EXT3: C60.+, C61.1, Q45.1, Q46.3, Q51.1, Q52.3, R102.2, R107.1, U21.2, U21.4
5V_MEAS: J14.1, JP10.1, Q4.4, Q5.2, Q6.4, Q7.2, Q8.4, Q9.2
5V_MEAS1: J31.1, JP28.1, Q15.4, Q16.2, Q19.4, Q20.2, Q21.4, Q22.2
5V_MEAS2: J47.1, JP42.1, Q28.4, Q29.2, Q32.4, Q33.2, Q34.4, Q35.2
5V_MEAS3: J63.1, JP56.1, Q41.4, Q42.2, Q45.4, Q46.2, Q47.4, Q48.2
!DTR!: Q1.4, R6.1, U2.13
!DTR!1: Q14.4, R36.1, U7.13
!DTR!2: Q27.4, R66.1, U13.13
!DTR!3: Q40.4, R96.1, U19.13
!GAUGE_ALERT!: JP12.1, R23.1, U6.5
!GAUGE_ALERT!1: JP24.1, R58.1, U12.5
!GAUGE_ALERT!2: JP38.1, R88.1, U18.5
!GAUGE_ALERT!3: JP52.1, R118.1, U24.5
!RTS!: Q1.1, R7.1, U2.14
!RTS!1: Q14.1, R35.1, U7.14
!RTS!2: Q27.1, R65.1, U13.14
!RTS!3: Q40.1, R95.1, U19.14
CC1: J2.A5, R3.2
CC2: J2.B5, R2.2
CC3: J21.B5, R33.2
CC4: J21.A5, R34.2
CC5: J37.B5, R63.2
CC6: J37.A5, R64.2
CC7: J53.B5, R93.2
CC8: J53.A5, R94.2
D+: J2.A6, J2.B6, J3.D+, U2.5
D+1: J21.A6, J21.B6, J22.D+, U7.5
D+2: J37.A6, J37.B6, J38.D+, U13.5
D+3: J53.A6, J53.B6, J54.D+, U19.5
D-: J2.A7, J2.B7, J3.D-, U2.6
D-1: J21.A7, J21.B7, J22.D-, U7.6
D-2: J37.A7, J37.B7, J38.D-, U13.6
D-3: J53.A7, J53.B7, J54.D-, U19.6
ESP32_0: Q1.3, S2.3, S2.4, U1.25
ESP32_1: Q14.3, S4.3, S4.4, U8.25
ESP32_2: Q27.3, S6.3, S6.4, U14.25
ESP32_3: Q40.3, S8.3, S8.4, U20.25
ESP32_ADC0: J11.6, J12.6, U1.4
ESP32_ADC1: J20.6, J25.6, U8.4
ESP32_ADC2: J20.5, J25.5, U8.5
ESP32_ADC3: J11.5, J12.5, U1.5
ESP32_ADC4: J11.2, J12.2, U1.8
ESP32_ADC5: J11.1, J12.1, U1.9
ESP32_ADC6: J11.4, J12.4, U1.6
ESP32_ADC7: J11.3, J12.3, U1.7
ESP32_ADC8: J20.4, J25.4, U8.6
ESP32_ADC9: J20.3, J25.3, U8.7
ESP32_ADC10: J20.1, J25.1, U8.9
ESP32_ADC11: J20.2, J25.2, U8.8
ESP32_ADC12: J36.6, J41.6, U14.4
ESP32_ADC13: J36.5, J41.5, U14.5
ESP32_ADC14: J36.4, J41.4, U14.6
ESP32_ADC15: J36.3, J41.3, U14.7
ESP32_ADC16: J36.1, J41.1, U14.9
ESP32_ADC17: J36.2, J41.2, U14.8
ESP32_ADC18: J52.6, J57.6, U20.4
ESP32_ADC19: J52.5, J57.5, U20.5
ESP32_ADC20: J52.4, J57.4, U20.6
ESP32_ADC21: J52.3, J57.3, U20.7
ESP32_ADC22: J52.1, J57.1, U20.9
ESP32_ADC23: J52.2, J57.2, U20.8
ESP32_EN: C1.1, J9.3, J10.3, Q1.6, R1.1, S1.3, S1.4, U1.3
ESP32_EN1: C23.1, J18.3, J24.3, Q14.6, R37.1, S3.3, S3.4, U8.3
ESP32_EN2: C40.1, J34.3, J40.3, Q27.6, R67.1, S5.3, S5.4, U14.3
ESP32_EN3: C57.1, J50.3, J56.3, Q40.6, R97.1, S7.3, S7.4, U20.3
ESP32_GPIO3: J19.3, J26.3, JP24.2, U8.26
ESP32_GPIO4: J7.3, J8.3, JP12.2, U1.26
ESP32_GPIO5: J19.7, J26.7, U8.28
ESP32_GPIO5_!CS!: J5.8, J6.8A, J6.8B, J15.2, U1.29
ESP32_GPIO5_!CS!1: J17.8A, J17.8B, J23.8, J29.2, U8.29
ESP32_GPIO5_!CS!2: J33.8A, J33.8B, J39.8, J45.2, U14.29
ESP32_GPIO5_!CS!3: J49.8A, J49.8B, J55.8, J61.2, U20.29
ESP32_GPIO6: J19.8, J26.8, U8.10
ESP32_GPIO7: J17.10A, J17.10B, J23.10, U8.11
ESP32_GPIO8: J17.9A, J17.9B, J23.9, U8.12
ESP32_GPIO9: J19.6, J26.6, U8.27
ESP32_GPIO11: J35.3, J42.3, JP38.2, U14.26
ESP32_GPIO12: J35.7, J42.7, U14.28
ESP32_GPIO12_TDI: J4.8, TP1.1, U1.14
ESP32_GPIO12_TDI1: J27.8, TP2.1, U8.14
ESP32_GPIO12_TDI2: J43.8, TP3.1, U14.14
ESP32_GPIO12_TDI3: J59.8, TP4.1, U20.14
ESP32_GPIO13: J35.8, J42.8, U14.10
ESP32_GPIO13_HDR: J7.4, J8.4, JP13.2
ESP32_GPIO13_HDR1: J19.4, J26.4, JP25.2
ESP32_GPIO13_HDR2: J35.4, J42.4, JP39.2
ESP32_GPIO13_HDR3: J51.4, J58.4, JP53.2
ESP32_GPIO13_TCK: J4.4, JP13.1, U1.16
ESP32_GPIO13_TCK1: J27.4, JP25.1, U8.16
ESP32_GPIO13_TCK2: J43.4, JP39.1, U14.16
ESP32_GPIO13_TCK3: J59.4, JP53.1, U20.16
ESP32_GPIO14: J33.10A, J33.10B, J39.10, U14.11
ESP32_GPIO14_HDR: J7.5, J8.5, JP14.2
ESP32_GPIO14_HDR1: J19.5, J26.5, JP26.2
ESP32_GPIO14_HDR2: J35.5, J42.5, JP40.2
ESP32_GPIO14_HDR3: J51.5, J58.5, JP54.2
ESP32_GPIO14_TMS: J4.2, JP14.1, U1.13
ESP32_GPIO14_TMS1: J27.2, JP26.1, U8.13
ESP32_GPIO14_TMS2: J43.2, JP40.1, U14.13
ESP32_GPIO14_TMS3: J59.2, JP54.1, U20.13
ESP32_GPIO15: J33.9A, J33.9B, J39.9, U14.12
ESP32_GPIO15_TDO: J4.6, U1.23
ESP32_GPIO15_TDO1: J27.6, U8.23
ESP32_GPIO15_TDO2: J43.6, U14.23
ESP32_GPIO15_TDO3: J59.6, U20.23
ESP32_GPIO16: J7.6, J8.6, U1.27
ESP32_GPIO17: J7.7, J8.7, U1.28
ESP32_GPIO18: J35.6, J42.6, U14.27
ESP32_GPIO18_SCK: D6.A, J5.5, J6.5A, J6.5B, J15.5, U1.30
ESP32_GPIO18_SCK1: D9.A, J17.5A, J17.5B, J23.5, J29.5, U8.30
ESP32_GPIO18_SCK2: D15.A, J33.5A, J33.5B, J39.5, J45.5, U14.30
ESP32_GPIO18_SCK3: D21.A, J49.5A, J49.5B, J55.5, J61.5, U20.30
ESP32_GPIO19_POCI: J5.6, J6.6A, J6.6B, J15.7, U1.31
ESP32_GPIO19_POCI1: J17.6A, J17.6B, J23.6, J29.7, U8.31
ESP32_GPIO19_POCI2: J33.6A, J33.6B, J39.6, J45.7, U14.31
ESP32_GPIO19_POCI3: J49.6A, J49.6B, J55.6, J61.7, U20.31
ESP32_GPIO20: J51.3, J58.3, JP52.2, U20.26
ESP32_GPIO21: J51.7, J58.7, U20.28
ESP32_GPIO22: J51.8, J58.8, U20.10
ESP32_GPIO23: J49.10A, J49.10B, J55.10, U20.11
ESP32_GPIO23_PICO: J5.7, J6.7A, J6.7B, J15.3, U1.37
ESP32_GPIO23_PICO1: J17.7A, J17.7B, J23.7, J29.3, U8.37
ESP32_GPIO23_PICO2: J33.7A, J33.7B, J39.7, J45.3, U14.37
ESP32_GPIO23_PICO3: J49.7A, J49.7B, J55.7, J61.3, U20.37
ESP32_GPIO24: J49.9A, J49.9B, J55.9, U20.12
ESP32_GPIO25: J7.8, J8.8, U1.10
ESP32_GPIO26: J5.10, J6.10A, J6.10B, U1.11
ESP32_GPIO27: J5.9, J6.9A, J6.9B, U1.12
ESP32_GPIO28: J51.6, J58.6, U20.27
ESP32_RXD0: J7.1, J8.1, R5.1, U1.34, U2.2
ESP32_RXD1: J19.1, J26.1, R31.1, U7.2, U8.34
ESP32_RXD2: J35.1, J42.1, R61.1, U13.2, U14.34
ESP32_RXD3: J51.1, J58.1, R91.1, U19.2, U20.34
ESP32_SCL: J5.1, J6.1A, J6.1B, J13.4, R28.1, U1.36, U6.7
ESP32_SCL1: J17.1A, J17.1B, J23.1, J28.4, R39.1, U8.36, U12.7
ESP32_SCL2: J33.1A, J33.1B, J39.1, J44.4, R69.1, U14.36, U18.7
ESP32_SCL3: J49.1A, J49.1B, J55.1, J60.4, R99.1, U20.36, U24.7
ESP32_SDA: J5.2, J6.2A, J6.2B, J13.3, R29.1, U1.33, U6.8
ESP32_SDA1: J17.2A, J17.2B, J23.2, J28.3, R40.1, U8.33, U12.8
ESP32_SDA2: J33.2A, J33.2B, J39.2, J44.3, R70.1, U14.33, U18.8
ESP32_SDA3: J49.2A, J49.2B, J55.2, J60.3, R100.1, U20.33, U24.8
ESP32_TXD0: J7.2, J8.2, R4.1, U1.35, U2.3
ESP32_TXD1: J19.2, J26.2, R32.1, U7.3, U8.35
ESP32_TXD2: J35.2, J42.2, R62.1, U13.3, U14.35
ESP32_TXD3: J51.2, J58.2, R92.1, U19.3, U20.35
GND: C1.2, C2.2, C3.2, C4.2, C5.2, C6.-, C7.2, C8.2, C9.-, C10.-, C11.2, C12.2, C13.2, C14.2, C15.2, C16.2, C17.2, J1.GND, J2.GND, J2.GND2, J3.GND, J4.3, J4.5, J4.7, J4.9, J5.4, J6.4A, J6.4B, J9.6, J9.7, J10.6, J10.7, J13.1, J15.6, J15.10, J15.11, J15.12, J15.13, J16.2, JP2.1, Q2.1, Q2.4, R2.1, R3.1, R8.1, R9.1, R11.1, R15.1, R16.1, R17.1, R18.1, R19.1, R20.1, R22.1, R24.1, R25.1, R26.1, R27.1, S1.1, S1.2, S2.1, S2.2, U1.1, U1.15, U1.38, U1.GND1, U1.GNDT1, U1.GNDT2, U1.GNDT3, U1.GNDT4, U1.GNDT5, U1.GNDT6, U1.GNDT7, U1.GNDT8, U2.1, U4.2, U5.2, U6.1, U6.4, U6.6, U6.9
GND2: C18.2, C19.2, C20.-, C21.2, C22.2, C23.2, C24.2, C25.2, C26.-, C27.2, C28.-, C29.2, C30.2, C31.2, C32.2, C33.2, C34.2, J17.4A, J17.4B, J18.6, J18.7, J21.GND, J21.GND2, J22.GND, J23.4, J24.6, J24.7, J27.3, J27.5, J27.7, J27.9, J28.1, J29.6, J29.10, J29.11, J29.12, J29.13, J30.GND, J32.2, JP27.1, Q17.1, Q17.4, R33.1, R34.1, R38.1, R41.1, R43.1, R44.1, R48.1, R49.1, R50.1, R51.1, R53.1, R54.1, R55.1, R56.1, R57.1, R59.1, S3.1, S3.2, S4.1, S4.2, U7.1, U8.1, U8.15, U8.38, U8.GND1, U8.GNDT1, U8.GNDT2, U8.GNDT3, U8.GNDT4, U8.GNDT5, U8.GNDT6, U8.GNDT7, U8.GNDT8, U10.2, U11.2, U12.1, U12.4, U12.6, U12.9
GND4: C35.2, C36.2, C37.-, C38.2, C39.2, C40.2, C41.2, C42.2, C43.-, C44.2, C45.-, C46.2, C47.2, C48.2, C49.2, C50.2, C51.2, J33.4A, J33.4B, J34.6, J34.7, J37.GND, J37.GND2, J38.GND, J39.4, J40.6, J40.7, J43.3, J43.5, J43.7, J43.9, J44.1, J45.6, J45.10, J45.11, J45.12, J45.13, J46.GND, J48.2, JP41.1, Q30.1, Q30.4, R63.1, R64.1, R68.1, R71.1, R73.1, R74.1, R78.1, R79.1, R80.1, R81.1, R83.1, R84.1, R85.1, R86.1, R87.1, R89.1, S5.1, S5.2, S6.1, S6.2, U13.1, U14.1, U14.15, U14.38, U14.GND1, U14.GNDT1, U14.GNDT2, U14.GNDT3, U14.GNDT4, U14.GNDT5, U14.GNDT6, U14.GNDT7, U14.GNDT8, U16.2, U17.2, U18.1, U18.4, U18.6, U18.9
GND6: C52.2, C53.2, C54.-, C55.2, C56.2, C57.2, C58.2, C59.2, C60.-, C61.2, C62.-, C63.2, C64.2, C65.2, C66.2, C67.2, C68.2, J49.4A, J49.4B, J50.6, J50.7, J53.GND, J53.GND2, J54.GND, J55.4, J56.6, J56.7, J59.3, J59.5, J59.7, J59.9, J60.1, J61.6, J61.10, J61.11, J61.12, J61.13, J62.GND, J64.2, JP55.1, Q43.1, Q43.4, R93.1, R94.1, R98.1, R101.1, R103.1, R104.1, R108.1, R109.1, R110.1, R111.1, R113.1, R114.1, R115.1, R116.1, R117.1, R119.1, S7.1, S7.2, S8.1, S8.2, U19.1, U20.1, U20.15, U20.38, U20.GND1, U20.GNDT1, U20.GNDT2, U20.GNDT3, U20.GNDT4, U20.GNDT5, U20.GNDT6, U20.GNDT7, U20.GNDT8, U22.2, U23.2, U24.1, U24.4, U24.6, U24.9
unnamed: R21.2, U5.1
unnamed: D5.C, R8.2
unnamed: D6.C, R9.2
unnamed: D4.C, R21.1
unnamed: D2.C, R4.2
unnamed: C8.1, U2.4
unnamed: D3.C, R5.2
unnamed: Q6.2, Q6.5, Q6.6, R17.2
unnamed: Q3.1, R14.2, R30.2
unnamed: Q6.3, Q7.1, R18.2
unnamed: Q2.3, R30.1
unnamed: Q4.2, Q4.5, Q4.6, R15.2
unnamed: Q8.2, Q8.5, Q8.6, R19.2
unnamed: R22.2, U5.5
unnamed: R10.1, R11.2, U3.1
unnamed: Q4.3, Q5.1, R16.2
unnamed: Q8.3, Q9.1, R20.2
unnamed: JP11.3, R28.2
unnamed: C21.1, U7.4
unnamed: JP11.1, R29.2
unnamed: Q2.2, R12.2
unnamed: Q2.5, Q2.6, R13.1
unnamed: Q10.3, Q11.1, R25.2
unnamed: Q1.5, R7.2
unnamed: Q1.2, R6.2
unnamed: Q10.2, Q10.5, Q10.6, R24.2
unnamed: Q14.5, R35.2
unnamed: Q12.3, Q13.1, R27.2
unnamed: Q12.2, Q12.5, Q12.6, R26.2
unnamed: Q14.2, R36.2
unnamed: D7.C, R32.2
unnamed: D8.C, R31.2
unnamed: JP23.3, R39.2
unnamed: JP23.1, R40.2
unnamed: R41.2, R42.1, U9.1
unnamed: Q15.2, Q15.5, Q15.6, R43.2
unnamed: Q15.3, Q16.1, R44.2
unnamed: Q17.2, R47.2
unnamed: Q17.5, Q17.6, R46.1
unnamed: Q19.3, Q20.1, R49.2
unnamed: Q19.2, Q19.5, Q19.6, R48.2
unnamed: Q21.2, Q21.5, Q21.6, R50.2
unnamed: Q21.3, Q22.1, R51.2
unnamed: R53.2, U11.5
unnamed: R52.2, U11.1
unnamed: D11.C, R52.1
unnamed: Q23.3, Q24.1, R55.2
unnamed: Q23.2, Q23.5, Q23.6, R54.2
unnamed: Q25.3, Q26.1, R57.2
unnamed: Q25.2, Q25.5, Q25.6, R56.2
unnamed: D12.C, R59.2
unnamed: D9.C, R38.2
unnamed: Q18.1, R45.2, R60.2
unnamed: Q17.3, R60.1
unnamed: C38.1, U13.4
unnamed: Q27.5, R65.2
unnamed: Q27.2, R66.2
unnamed: D13.C, R62.2
unnamed: D14.C, R61.2
unnamed: JP37.3, R69.2
unnamed: JP37.1, R70.2
unnamed: R71.2, R72.1, U15.1
unnamed: Q28.2, Q28.5, Q28.6, R73.2
unnamed: Q28.3, Q29.1, R74.2
unnamed: Q30.2, R77.2
unnamed: Q30.5, Q30.6, R76.1
unnamed: Q32.3, Q33.1, R79.2
unnamed: Q32.2, Q32.5, Q32.6, R78.2
unnamed: Q34.2, Q34.5, Q34.6, R80.2
unnamed: Q34.3, Q35.1, R81.2
unnamed: R83.2, U17.5
unnamed: R82.2, U17.1
unnamed: D17.C, R82.1
unnamed: Q36.3, Q37.1, R85.2
unnamed: Q36.2, Q36.5, Q36.6, R84.2
unnamed: Q38.3, Q39.1, R87.2
unnamed: Q38.2, Q38.5, Q38.6, R86.2
unnamed: D18.C, R89.2
unnamed: D15.C, R68.2
unnamed: Q31.1, R75.2, R90.2
unnamed: Q30.3, R90.1
unnamed: C55.1, U19.4
unnamed: Q40.5, R95.2
unnamed: Q40.2, R96.2
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

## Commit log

2021-12-21 Added initial schematic version.
    [RedBoard_ESP32.brd, RedBoard_ESP32.sch]
2021-12-21 Added missing Vin symbol.
    [RedBoard_ESP32.brd, RedBoard_ESP32.sch]
2021-12-21 Changed pin name from /SS to /CS
    [RedBoard_ESP32.brd, RedBoard_ESP32.sch]
2021-12-22 Preliminary routed board, no labels yet.
    [RedBoard_ESP32.brd, RedBoard_ESP32.sch]
2021-12-23 Added board labels.
    [RedBoard_ESP32.brd, RedBoard_ESP32.sch]
2021-12-27 Added ordering instructions; added production files.
    [RedBoard_ESP32-Panel.brd, RedBoard_ESP32.brd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]
2022-01-03 Changed board per Nathan's recommendations; added production files.
    - Changed SPI pins nomenclatures.
    - Fixed silkscreens.
    - Replaced SD card socket with an updated one.
    [RedBoard_ESP32-Panel.brd, RedBoard_ESP32.brd, RedBoard_ESP32.sch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]
2022-01-07 Moved SD card connector; updated RST/RESET flags.
    [RedBoard_ESP32-Panel.brd, RedBoard_ESP32.brd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]
2022-01-07 Added version number to filename; updated production files.
    [RedBoard_ESP32-Panel.brd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]
2022-01-11 Added Test Point per Eric Orosel request.
    [RedBoard_ESP32_v01-Panel.brd, RedBoard_ESP32_v01.brd, RedBoard_ESP32_v01.sch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]
2022-01-12 Fixed trace on bottom side, regenerated panel file.
    [RedBoard_ESP32_v01-Panel.brd, RedBoard_ESP32_v01.brd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]
2022-01-12 Moved BOM file; updated production files.
    [bom_output.csv]
2022-01-13 Changed labels as suggested by Chris; updated production files.
    [RedBoard_ESP32_v01-Panel.brd, RedBoard_ESP32_v01.brd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]
2022-01-13 Updated silkscreen.
    [RedBoard_ESP32_v01-Panel.brd, RedBoard_ESP32_v01.brd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]
2022-01-13 Updated to reflect board name.
2022-01-13 Renamed repo/filename to match board name.
    [RedBoard_ESP32_v01-Panel.brd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]
2022-01-17 Implemented changes suggested by Pete Lewis.
    [SparkFun_IoT_RedBoard-ESP32_v01-Panel.brd, SparkFun_IoT_RedBoard-ESP32_v01.brd, SparkFun_IoT_RedBoard-ESP32_v01.sch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]
2022-01-17 Fixed silkscreen and via interference on bottom layer;
    [SparkFun_IoT_RedBoard-ESP32_v01-Panel.brd, SparkFun_IoT_RedBoard-ESP32_v01.brd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]
2022-01-18 Updated design per Engineering checklist.
    [SparkFun_IoT_RedBoard-ESP32_v01-Panel.brd, SparkFun_IoT_RedBoard-ESP32_v01.brd, SparkFun_IoT_RedBoard-ESP32_v01.sch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]
2022-01-19 Updated design per Engineering recommendation.
    [SparkFun_IoT_RedBoard-ESP32_v01-Panel.brd, SparkFun_IoT_RedBoard-ESP32_v01.brd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]
2022-01-31 Flipped Q3, added 100R resistor to Q3's gate and changed panel to 2x2 boards
    [SparkFun_IoT_RedBoard-ESP32_v01-Panel.brd, SparkFun_IoT_RedBoard-ESP32_v01.brd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]
2022-01-31 Updated BOM
    [bom_output.csv]
2022-01-31 Updated ordering instructions solder mask color.
    [SparkFun_IoT_RedBoard-ESP32_v01.brd]
2022-03-09 Increase resistors on perfect diodes to reduce quiescent current
    [SparkFun_IoT_RedBoard-ESP32_v01.brd, SparkFun_IoT_RedBoard-ESP32_v01.sch]
2022-05-02 Update cosmetic components and silk
    Change power LED to red
    Change charge LED to yellow
    Change green/yellow LED resistors to 1k
    Change red LED resistor to 2.2k
    Update some top pin silk labels to include pin numbers
    Fix RX silk to be "RX-0" instead of "RX-1"
    [SparkFun_IoT_RedBoard-ESP32_v01.brd, SparkFun_IoT_RedBoard-ESP32_v01.sch]
2022-05-02 Adjust LED jumper
    New position allows better label placement
    [SparkFun_IoT_RedBoard-ESP32_v01.brd]
2022-05-04 Improve GND continuity
    Add several GND vias
    Adjust some traces to allow GND to pour through
    [SparkFun_IoT_RedBoard-ESP32_v01.brd]
2022-05-04 Add "revised by" and change version number
    [SparkFun_IoT_RedBoard-ESP32_v01.brd, SparkFun_IoT_RedBoard-ESP32_v01.sch]
2022-05-04 Change PTC Fuse
    Reduce current rating of PTC
    Move PTC to 5V_MEAS to protect all power inputs rather than just USB
    [SparkFun_IoT_RedBoard-ESP32_v01.brd, SparkFun_IoT_RedBoard-ESP32_v01.sch]
2022-05-04 Add addressable status LED
    [SparkFun_IoT_RedBoard-ESP32_v01.brd, SparkFun_IoT_RedBoard-ESP32_v01.sch]
2022-05-06 Design review updates
    Rename files to remove "v01"
    Update libraries
    Adjust traces under SD card for keepout region
    Change ESP32 footprint from narrow to standard
    Change USB-C connector to 4-layer version
    Add USB shield jumper
    Move CC resistor positions
    Adjust parts to be on grid where possible
    Move Qwiic logo to top silk (also adjust Reset silk to avoid confusion)
    Adjust layer numbers in copper to not overlap
    Remove C14
    Increase current rating of D1
    Add silk to addressable LED
    Remove extraneous mill lines
    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
    [SparkFun_IoT_RedBoard-ESP32.brd, SparkFun_IoT_RedBoard-ESP32.sch]
2022-05-09 More design review updates
    Add center positive silk marker to barrel jack
    Fix air wire errors in ULP by connecting with traces
    Add SD card detection with NO jumper to GPIO16
    [SparkFun_IoT_RedBoard-ESP32.brd, SparkFun_IoT_RedBoard-ESP32.sch]
2022-05-10 Add NC jumper for each LED
    Also fix barrel jack voltage silk
    [SparkFun_IoT_RedBoard-ESP32.brd, SparkFun_IoT_RedBoard-ESP32.sch]
2022-05-10 Checklist update
    Approve DRC errors on jumpers
    Add space between traces on layer 2
    [SparkFun_IoT_RedBoard-ESP32.brd]
2022-05-11 Design review updates
    Change IO2 to GPIO2 in top silk
    Remove via restrict regions
    Remove test point silk
    [SparkFun_IoT_RedBoard-ESP32.brd]
2022-05-11 Add production files for v02
    [SparkFun_IoT_RedBoard-ESP32-Panel.GBL, SparkFun_IoT_RedBoard-ESP32-Panel.GBO, SparkFun_IoT_RedBoard-ESP32-Panel.GBP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]
2022-05-26 Fix A4 and A5 bottom silk labels
    [SparkFun_IoT_RedBoard-ESP32.brd]
2022-05-31 Update version number to v10
    [SparkFun_IoT_RedBoard-ESP32.brd, SparkFun_IoT_RedBoard-ESP32.sch]
2022-05-31 Design review updates
    Add decoupling cap for WS2812
    Move SparkFun logo in top silk
    Add GND via for 3V regulator
    Change I2C label to use superscript 2
    Remove extraneous lines in schematic
    Add warnings about ESP32 boot pins and ADC2/WiFi to schematic
    [SparkFun_IoT_RedBoard-ESP32.brd, SparkFun_IoT_RedBoard-ESP32.sch]
2022-06-01 Design Review Updates
    Change "Revised by" to vector font in tDocu
    Rename jumpers based on their functions
    Add GND trace between GPIO 16/17 in layer 3
    [SparkFun_IoT_RedBoard-ESP32.brd, SparkFun_IoT_RedBoard-ESP32.sch]
2022-06-01 Design review updates
    Clean up SHLD jumper in schematic
    Clean up boot mode table
    Doot
    Move C8 closer to CH340
    Fix natural bridges
    Improve GND continuity
    Add 10uF cap to uSD
    Switch 3V regulator
    Replace LED footprints with non-hidden silk
    Add NO jumper between RGB LED DO and NC pin
    [SparkFun_IoT_RedBoard-ESP32.brd, SparkFun_IoT_RedBoard-ESP32.sch]
2022-06-02 Pre-production updates
    Update regulator current in schematic
    Change "LED DO" silk label to "NC/LED DO"
    [SparkFun_IoT_RedBoard-ESP32.brd, SparkFun_IoT_RedBoard-ESP32.sch]
2022-06-02 Add production files
    [SparkFun_IoT_RedBoard-ESP32-Panel.brd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]
2022-06-02 Update panel with fiducials on top/bottom
    [SparkFun_IoT_RedBoard-ESP32-Panel.brd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]
2022-06-02 Moved panel fiducial and generated gerbers
    [SparkFun_IoT_RedBoard-ESP32-Panel.brd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]
2022-06-02 Remove old gerber zip
2022-06-02 Fix PROD_ID of new regulator
    Didn't update when it was replaced for some reason
    [SparkFun_IoT_RedBoard-ESP32-Panel.brd, SparkFun_IoT_RedBoard-ESP32.brd, SparkFun_IoT_RedBoard-ESP32.sch]

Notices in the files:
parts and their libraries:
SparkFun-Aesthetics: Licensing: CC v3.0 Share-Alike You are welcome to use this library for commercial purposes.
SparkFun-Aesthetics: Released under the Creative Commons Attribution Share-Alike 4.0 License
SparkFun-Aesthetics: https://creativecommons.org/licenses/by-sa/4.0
